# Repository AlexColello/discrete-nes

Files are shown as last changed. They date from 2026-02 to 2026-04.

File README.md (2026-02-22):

# Discrete NES - Every Gate Visible

A discrete logic implementation of the Nintendo Entertainment System where **EVERY single gate output and EVERY memory bit is visible via LED**. Watch a complete NES flip every bit in real-time.

## Project Vision

This is an educational and artistic hardware project showcasing the complete internal state of a working NES using **TI Little Logic (SN74LVC1G) in DSBGA packages** — tiny ICs with the **bare silicon die visible** on top. Thousands of exposed silicon dies interspersed with glowing 0402 SMD LEDs.

**This is one of the largest discrete logic projects ever attempted:**
- Estimated **10,000+ LEDs** across all boards
- **Thousands of single-gate ICs** (TI Little Logic, DSBGA — bare silicon visible)
- Multiple PCBs with SMD assembly
- Complete **cycle-accurate NES** implementation in visible discrete logic

## The Aesthetic

Each logic gate is a single DSBGA package (1.75 x 1.25mm) with the bare silicon wafer pattern visible on top. Between them, tiny 0402 SMD LEDs (1.0 x 0.5mm) glow to show every gate output state. The LEDs are deliberately smaller than the ICs so the silicon dies are the visual focus.

## Board Structure

- **RAM Board** - 8-byte prototype (starting point, validates DSBGA assembly)
  - ~180 DSBGA ICs, ~115 LEDs, ~115 resistors
  - ~60x80mm PCB

- **CPU Board** (2A03 - 6502-based with APU)
  - ~5,000 LEDs, ~5,000 ICs

- **PPU Board** (2C02 - Picture Processing Unit)
  - ~3,000 LEDs, ~3,000 ICs

- **Glue Logic/Interconnect Boards**

## Technology Stack

- **Logic ICs:** TI Little Logic SN74LVC1G series (DSBGA — bare silicon die visible)
- **LEDs:** 0402 SMD (smaller than ICs for aesthetic balance)
- **LED Drive:** Direct from LVC outputs (up to 24mA capable, target 2mA)
- **Schematic Generation:** Python + kiutils
- **PCB Layout:** kiutils + manual routing
- **Logic Reference:** MiSTer NES core (Verilog/SystemVerilog)
- **Design Tool:** KiCad 8.x
- **Assembly:** Solder paste stencil + hot air reflow

## Repository Structure

```
discrete-nes/
├── shared/               # Shared libraries and utilities
│   ├── kicad-lib/       # KiCad symbols, footprints, 3D models
│   └── python/          # Python generation utilities
├── boards/              # Individual board projects
│   ├── ram-prototype/   # First prototype board (8 bytes)
│   ├── cpu-2a03/        # CPU board
│   ├── ppu-2c02/        # PPU board
│   └── interconnect/    # Board interconnection
├── reference/           # FPGA reference documentation
└── tools/               # Development tools
```

## Getting Started

### Prerequisites

- Python 3.8+
- KiCad 8.x
- Git

### Setup

1. **Clone this repository:**
   ```bash
   git clone https://github.com/yourusername/discrete-nes.git
   cd discrete-nes
   ```

2. **Set up Python environment:**
   ```bash
   python -m venv venv
   source venv/bin/activate  # On Windows: venv\Scripts\activate
   pip install -r requirements.txt
   ```

3. **Review the reference documentation:**
   See `reference/README.md` for information about accessing the MiSTer NES core used as logic reference.

## Development Workflow

1. **Design circuit manually** in KiCad (first cell/module)
2. **Document the pattern** for script generation
3. **Write Python scripts** to generate repetitive structures
4. **Generate schematics** using kiutils
5. **Place components** on PCB (scripted DSBGA grid layout)
6. **Route manually** or use assisted tools
7. **Validate** with DRC/ERC
8. **Fabricate and reflow assemble**

## Current Status

**Phase 1: Project Setup** - COMPLETE

- [x] Repository structure created
- [x] Python utilities framework
- [x] Reference documentation
- [x] KiCad shared libraries (symbols/footprints)
- [x] Migration to TI Little Logic DSBGA
- [ ] RAM prototype circuit design (next)

## Power Requirements

With an LED on every gate output, power consumption is LED-dominated:

- RAM prototype (8 bytes): ~0.25A at 3.3V (~0.8W)
- Full system: ~12A+ at 3.3V (~40W)

## Educational Value

This project provides unparalleled visibility into:
- How a CPU executes instructions (watch the program counter increment!)
- Memory addressing and data flow
- Video frame generation in real-time
- Every internal state transition

Perfect for computer science education, maker spaces, and museum exhibits.

## Resources

- **MiSTer NES Core:** https://github.com/MiSTer-devel/NES_MiSTer (logic reference)
- **OpenTendo:** https://github.com/Redherring32/OpenTendo (NES reproduction PCBs)
- **NES Dev Wiki:** https://www.nesdev.org/wiki/
- **Visual 6502:** http://www.visual6502.org/

## Contributing

This is an ambitious project that will evolve over time. Contributions welcome:
- Circuit design improvements
- Python generation utilities
- Documentation
- Testing and validation

## License

TBD - To be determined

## Acknowledgments

- **MiSTer Project** - For the excellent NES core used as logic reference
- **Texas Instruments** - For the Little Logic product line
- **KiCad Project** - For the outstanding open-source EDA tools
- **Ben Eater** - For inspiring discrete logic projects
- **NES Dev Community** - For extensive documentation

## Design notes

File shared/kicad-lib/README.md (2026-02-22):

# Shared KiCad Libraries

This directory contains shared symbol and footprint libraries for the discrete NES project.

## Structure

- **symbols/** - Schematic symbols
  - `LittleLogic_LVC.kicad_sym` - TI Little Logic SN74LVC1G single-gate ICs
  - `LED_Indicators.kicad_sym` - 0402 SMD LED symbols
  - `Power_Discrete.kicad_sym` - Power connectors and regulators

- **footprints/** - PCB footprints
  - `DSBGA_Packages.pretty/` - DSBGA (NanoFree/YZP) packages for TI Little Logic
  - `LED_SMD.pretty/` - 0402 SMD LED footprints
  - `Connectors_Discrete.pretty/` - Board interconnect connectors

- **3d-models/** - 3D models for PCB visualization

## Using These Libraries

The library tables (`sym-lib-table` and `fp-lib-table`) use relative paths with `${KIPRJMOD}` to reference these shared libraries from any board project.

When creating a new board project:

1. Copy `sym-lib-table` to your project directory
2. Copy `fp-lib-table` to your project directory
3. KiCad will automatically find the shared libraries

## Creating New Symbols/Footprints

New symbols and footprints can be added using KiCad's library editors or programmatically using kiutils.

### Common Components Needed:

**Logic Gates (1 gate per DSBGA package):**
- SN74LVC1G00 - Single 2-input NAND (YZP, 5-ball)
- SN74LVC1G02 - Single 2-input NOR (YZP, 5-ball)
- SN74LVC1G04 - Single Inverter (YZP, 5-ball)
- SN74LVC1G08 - Single 2-input AND (YZP, 5-ball)
- SN74LVC1G11 - Single 3-input AND (YZP, 6-ball)
- SN74LVC1G32 - Single 2-input OR (YZP, 5-ball)
- SN74LVC1G86 - Single 2-input XOR (YZP, 5-ball)

**Flip-Flops:**
- SN74LVC1G79 - Single D flip-flop, Q only (YZP, 5-ball DSBGA)
- SN74LVC1G74 - Single D flip-flop, Q/Q-bar/preset/clear (DQE, 8-pin X2SON)

**Buffers and Drivers:**
- SN74LVC1G07 - Single buffer, open drain (YZP, 5-ball)
- SN74LVC1G125 - Single tri-state buffer (YZP, 5-ball)

**LEDs:**
- 0402 SMD LEDs (various colors)
- 0402 SMD resistors for current limiting

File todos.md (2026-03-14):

# Discrete NES - TODOs

## RAM Prototype - PCB (Phase 2 Step 3)

### Layout issues
- [x] **Layer test table In1 row broken** — fixed: added In1.Cu copper pour zone for the In1 Fill row (was missing because In1.Cu has no full-board zone unlike B.Cu/In2.Cu)
- [x] **COL_SEL and DEC4 headers misplaced** — fixed: J3 (COL_SEL) moved from test grid area to below column_select group; J2/J4 (DEC3/DEC4) remain near addr_decoder/control_logic area
- [x] **Column select LEDs need nicer presentation** — fixed: 16 output LEDs (COL_SEL_0-15) in a dedicated row above the level-2 ANDs (3.5mm gap), remaining rows keep inline LEDs
- [x] **Row control read/write gates layout** — fixed: write + read gates now horizontal (side by side), stride matched to byte row stride (7.0mm) so each row_ctrl block aligns with its byte row
- [x] **Extra spacing on byte silkscreen outlines** — fixed: reduced SILK_MARGIN from 3.0mm to 1.5mm
- [ ] **Layer test table: add hashed fill row** — add a row demonstrating hashed/crosshatch copper fill pattern

### Pre-routing rework needed
- [ ] **NAND routing rework for IC_CELL_H=3.0** — NAND local connections (preroute_nand_connections) are skipped and left to the autorouter because escape path offsets were tuned for IC_CELL_H=3.5. Needs full rework for current 3.0 geometry (generate_pcb.py:2325-2329)
- [ ] **DFF->Buffer routing** — currently skipped (autorouter via In1.Cu). Data bus via at ic_cx-0.50 leaves 0mm clearance to BUF A pin on F.Cu, so this must go through In1.Cu (generate_pcb.py:2339-2341)
- [ ] **D* data bus fanout prerouting** — preroute the fanout of D0-D7 data bus traces to byte groups
- [ ] **Column select fanout prerouting** — preroute the COL_SEL signal distribution traces
- [ ] **Row select trace prerouting** — locally preroute all ROW_SEL traces from row control to byte groups. Must happen after bytes are fully locally routed (depends on NAND, DFF->Buffer, and data bus prerouting being done first)

### Footprint rework
- [x] **Create custom DSBGA footprints** — done: removed silkscreen pin-1 triangle, reduced courtyard to 0.3mm offset from chip outline (DSBGA-5: ±0.75×±1.0, DSBGA-6: ±0.8×±1.0, DSBGA-8: ±0.8×±1.3)

- [ ] **Pin connector 3D models rotated 180°** — all pin header connectors (J1-J4) have their 3D model rotated 180° around the square pad in the 3D viewer. Need to fix the model rotation in the footprint or placement
- [ ] **Add 3D models for DSBGA-5 and DSBGA-6 footprints** — custom footprints currently lack 3D models for KiCad 3D viewer
- [ ] **Investigate moving resistors to front of board** — currently on B.Cu for space reasons, but this makes assembly and rework harder. Explore using a smaller resistor footprint (e.g., 0201) to fit R on F.Cu alongside the LED

### Post-footprint-rework
- [ ] **Compress PCB layout** — once custom footprints with tighter courtyards are in place, reduce component spacing / cell dimensions to take advantage of the smaller footprints

### Autorouter / manual routing
- [ ] **Run FreeRouting autorouter** on current PCB to complete remaining unrouted nets
- [ ] **Verify post-routing DRC** — run `verify_pcb.py --post-routing` after routing completes
- [ ] **Review routed result** — check trace quality, 45-degree angles, no unnecessary vias

### PCB validation
- [ ] **Fabrication review** — verify board meets Elecrow specs (min via 0.8mm/0.4mm, trace/space, etc.)
- [ ] **Add JLCPCB DRC rules** — include JLCPCB design rule checks alongside Elecrow for fab flexibility
- [ ] **Power distribution review** — check VCC/GND plane integrity, via current capacity
- [ ] **Generate gerbers** and do final visual inspection
- [ ] **Generate BOM** for ordering

## RAM Prototype - Schematic

### Signal ordering / spacing
- [x] **Row select pin order vs inverter order swapped** — fixed: reversed A0-A6 order on addr_decoder sheet block and internally (A6 at top, A0 at bottom) to match connector visual order at 180°
- [x] **More space between connector and logic** — fixed: increased PCB gap from GROUP_GAP_X to GROUP_GAP_X*3 (6mm extra between connector group and addr_decoder)

### Wire routing / overlaps
- [ ] **Wire overlaps throughout** — verify_schematics.py check passes but visual issues may remain. Needs user review in KiCad to identify specific problem areas
- [ ] **Root sheet routing nonsensical** — wire routing on the root sheet doesn't make sense, looks like connector pins are not being positioned/moved correctly
- [ ] **Pin names missing on connector** — connector pins should have visible names next to them
- [ ] **Hierarchical labels outside sheet margins** — verify_schematics.py check passes but visual issues may remain. Needs user review in KiCad to identify specific problem areas

### PCB generate script
- [ ] **Fix layout ASCII art in generate_pcb.py** — the ASCII art diagram at the top of the file doesn't accurately reflect the current board layout

### Visual / layout issues
- [ ] **Text drawn on top of components** — component text (references, values) overlapping other components where it shouldn't be
- [ ] **VCC/GND symbols touching tip-to-tip** — verify_schematics.py doesn't catch this. Needs user review in KiCad to identify specific problem areas

### Component selection
- [ ] **Choose LED part numbers and colors** — select specific 0402 LED parts. Consider using different colors to visually distinguish gate types or functional purposes (e.g., address decoder vs data path vs control signals)
- [ ] **Choose resistor values** — calculate and select appropriate current-limiting resistor values for each LED color at 3.3V (different Vf per color means different R values)

### Architecture improvement
- [ ] **Simplify LED indicators** — investigate using a symbol, sub-sheet, or other encapsulation method to hold the LED+resistor chain so that LEDs don't have to be drawn inline in every gate logic sheet. Would significantly reduce schematic clutter and simplify the generate scripts

## RAM Prototype - Fabrication (Phase 2 Step 5)

- [ ] Order PCBs + solder paste stencil
- [ ] Order components (DSBGA ICs, 0402 LEDs, 0402 resistors, pin headers)
- [ ] Cost estimation for prototype run
- [ ] Reflow assembly and test

## Shared Library (kicad_gen)

- [x] **DSBGA footprint files modified** — these are auto-generated by generate_pcb.py on each run (create_dsbga_footprints), no manual commit needed
- [ ] Consider adding automated tests for kicad_gen modules

## Future Boards

### CPU (2A03)
- [ ] Study MiSTer NES core Verilog for 6502 CPU
- [ ] Gate-level synthesis (Yosys?) of CPU logic
- [ ] Map to SN74LVC1G discrete gates
- [ ] Plan power distribution for ~5000 LEDs (~6A at 3.3V)

### PPU (2C02)
- [ ] Study MiSTer NES core Verilog for PPU
- [ ] Gate-level synthesis of PPU logic
- [ ] Plan power distribution for ~3000 LEDs (~4A at 3.3V)

### System Integration
- [ ] Board interconnect design (backplane or cable)
- [ ] System-level power distribution (12A+ at 3.3V total)
- [ ] Clock distribution across boards

## HDL Parser / Verilog-to-Gates

- [ ] Enhance `verilog_to_gates.py` for real synthesis
- [ ] Evaluate Yosys as synthesis backend
- [ ] Test with MiSTer NES modules

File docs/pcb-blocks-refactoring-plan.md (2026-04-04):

# Refactoring Plan: Composable PCB Layout Block Classes

## Context

`generate_pcb.py` is 4868 lines with 44 functions. The layout and prerouting logic is monolithic — every byte group, decoder column, and routing pattern is handled by standalone functions that take raw `(pcb, netlist_data)` and rely on global knowledge of where everything was placed. This makes it impossible to reuse blocks across boards (the full 2KB board at `boards/ram/` has no PCB generation at all yet — it would require copy-pasting thousands of lines).

The core problem: **there's no object that represents "a placed group of components with its routing"**. Layout positions are computed in `main()`, prerouting functions re-discover positions by scanning all footprints, and there's no way to compose a byte group + decoder + bus routing as reusable units.

## Approach

Introduce block classes that own their layout, placement, and prerouting. Each block:
- Knows its own relative component positions
- Places itself on a `PCBBuilder` at an absolute (x, y) origin
- Pre-routes its internal connections
- Exposes interface points (pin positions, bus stubs) for inter-block wiring

### Key Files

| File | Change |
|---|---|
| `shared/python/kicad_gen/pcb_blocks.py` | **NEW** — Block base class + concrete blocks |
| `shared/python/kicad_gen/__init__.py` | Export new block classes |
| `boards/ram-prototype/scripts/generate_pcb.py` | Refactor to use blocks |

## Block Class Design

### Base: `PCBBlock`

```python
class PCBBlock:
    """Base class for a composable PCB component group."""
    
    def __init__(self):
        self.origin = (0.0, 0.0)       # absolute placement origin
        self._placements = []           # [(comp_dict, rel_x, rel_y), ...]
        self._placed_refs = []          # refs after placement
    
    def layout(self, components):
        """Compute relative placements from netlist components. Sets self._placements."""
        raise NotImplementedError
    
    def place(self, pcb, x, y, netlist_data):
        """Place all components at absolute (x, y) origin. Returns list of refs placed."""
        self.origin = (x, y)
        ...
    
    def preroute(self, pcb, netlist_data):
        """Pre-route internal connections. Called after place()."""
        pass
    
    def get_bounds(self):
        """Return (min_x, min_y, max_x, max_y) in absolute coords."""
        ...
    
    def get_pin(self, ref, pad):
        """Get absolute position of a pad. Shortcut for pcb.get_pad_position()."""
        ...
    
    def get_interface(self):
        """Return dict of named interface points for inter-block wiring."""
        return {}
```

### `ByteGroupBlock` — The highest-value abstraction

Owns: 1 NAND (74LVC2G00) + 8 DFF + 8 BUF + 18 LEDs + 18 Rs = ~54 components per byte.

Currently spread across:
- `layout_byte_group()` (~80 lines) — relative positioning
- `preroute_dff_to_buffer()` (~120 lines) — DFF Q → BUF A via In1.Cu
- `preroute_dff_buf_gnd()` (~60 lines) — shared GND Z-route
- `preroute_dff_buf_data()` (~65 lines) — data pin mirrored Z-route
- `preroute_dff_buf_vcc()` (~80 lines) — VCC L-route via In2.Cu
- `preroute_clk_fanout()` (~65 lines) — CLK horizontal bus
- `preroute_oe_fanout()` (~65 lines) — OE horizontal bus  
- `preroute_nand_connections()` (~280 lines) — NAND output/input routing
- `preroute_nand_leds()` (~110 lines) — NAND LED routing
- `preroute_ic_to_led()` (DFF/BUF portions, ~50 lines) — IC→LED anode
- Parts of `preroute_led_to_resistor()`, `preroute_r_gnd()`, `preroute_power_vias()`

Total: ~1000 lines of byte-specific code → encapsulated as one class with `layout()`, `place()`, `preroute()`.

```python
class ByteGroupBlock(PCBBlock):
    def layout(self, components):
        """Current layout_byte_group() logic."""
        
    def preroute(self, pcb, netlist_data):
        """All internal byte routing:
        - DFF-BUF pairs (Q→A, GND, VCC, data)
        - CLK fanout bus
        - OE fanout bus  
        - NAND connections + NAND LEDs
        - IC→LED, LED→R, R→GND for byte components
        """
    
    def get_interface(self):
        """Returns positions for inter-block wiring:
        - clk_bus: (x_start, x_end, y) — CLK bus entry point
        - oe_bus: (x_start, x_end, y) — OE bus entry point
        - nand_colsel_pin: (x, y) — COL_SEL input to NAND
        - nand_wen_pin: (x, y) — WRITE_EN input to NAND
        - nand_ren_pin: (x, y) — READ_EN input to NAND
        - dff_data_vias: [(x, y, net), ...] — D0-D7 data bus via positions
        """
```

### `DecoderColumnBlock` — Vertical IC column

Owns: N ICs + N LEDs + N Rs in a vertical column with configurable spacing.

Currently: `_place_col()` closure in `main()` + the addr_decoder / column_select custom layout blocks.

```python
class DecoderColumnBlock(PCBBlock):
    def __init__(self, cell_h=4.0, led_offset_x=1.5, r_horiz_offset=1.86):
        ...
    
    def layout(self, ic_cells, total_h=None, ys=None):
        """Place cells vertically centered within total_h, or at explicit ys."""
    
    def preroute(self, pcb, netlist_data):
        """IC→LED, LED→R, power vias for this column."""
    
    def get_interface(self):
        """Returns IC pin positions by index for inter-column wiring."""
```

### `DecoderBlock` — Multi-column decoder (addr_decoder or column_select)

Composes multiple `DecoderColumnBlock`s:

```python
class DecoderBlock(PCBBlock):
    def __init__(self, column_configs):
        """column_configs: list of (num_cells, cell_h, col_spacing) per column."""
        self.columns = []  # list of DecoderColumnBlock
    
    def layout(self, components):
        """Split components into columns, layout each."""
        
    def preroute(self, pcb, netlist_data):
        """Route all columns' internal connections."""
```

### `RowControlBlock` — Vertical AND gate pair

Owns: 2 ANDs + 2 LEDs + 2 Rs.

```python
class RowControlBlock(PCBBlock):
    def __init__(self, gate_spacing=2.3):
        ...
```

### `ConnectorBlock` — Connector + bus indicator LEDs

Owns: 1 connector + matched LED+R pairs aligned to pin Y positions.

### `PowerSupplyBlock` — Buck converter + passives + zones

Owns: TPS546D24A + caps + inductor + resistors + copper pour zones.

## Inter-Block Wiring

After all blocks are placed and internally prerouted, the remaining preroute functions handle inter-block connections. These stay as functions (not methods) because they span multiple blocks:

- `preroute_enable_buses()` — row_ctrl → byte CLK/OE buses
- `preroute_ctrl_enable_trunks()` — control_logic → row_ctrl
- `preroute_col_sel_vias()` / `preroute_colsel_fanout()` — column_select → bytes
- `preroute_column_dbus()` / `preroute_dbus_fanout()` / `preroute_dbus_to_connector()` — data bus across all bytes
- `preroute_connector_leds()` — connector → bus LEDs
- `preroute_coladdr_to_colsel()` — connector → column_select

These inter-block routers can use `block.get_interface()` to discover connection points instead of scanning all footprints.

## How `main()` Changes

Before (pseudocode):
```python
# 200 lines computing layouts for each group type (custom per group)
# 200 lines computing absolute positions
# 200 lines placing components with for loops
# 30 lines calling 20+ preroute functions
```

After:
```python
# Create blocks
bytes = [ByteGroupBlock() for _ in range(8)]
decoder = DecoderBlock(addr_decoder_config)
col_select = DecoderBlock(col_select_config)  
row_ctrls = [RowControlBlock() for _ in range(4)]
connector = ConnectorBlock()
power = PowerSupplyBlock()

# Layout (from netlist components)
for i, name in enumerate(byte_names):
    bytes[i].layout(groups[name])
decoder.layout(groups["addr_decoder"])
# ... etc

# Compute positions (board-specific arrangement)
# ... ~50 lines of position math (reduced from ~200)

# Place + preroute all blocks
for block in all_blocks:
    block.place(pcb, x, y, netlist_data)
    block.preroute(pcb, netlist_data)

# Inter-block routing
route_enable_buses(pcb, row_ctrls, bytes, netlist_data)
route_data_bus(pcb, bytes, connector, netlist_data)
# ... etc
```

## Implementation Order

1. **Create `pcb_blocks.py`** with `PCBBlock` base class and `ByteGroupBlock`
   - Move `layout_byte_group()` → `ByteGroupBlock.layout()`
   - Move byte-specific preroute functions → `ByteGroupBlock.preroute()`
   - Wire up `get_interface()` returning bus stubs and NAND pins

2. **Add `DecoderColumnBlock`** and **`DecoderBlock`**
   - Move `_place_col()` and addr_decoder/column_select layout → block classes
   - Move IC→LED, LED→R, power via routing for decoder ICs

3. **Add `RowControlBlock`**, **`ConnectorBlock`**, **`PowerSupplyBlock`**

4. **Refactor `main()`** to compose blocks
   - Keep inter-block routing as standalone functions that take block references
   - Inter-block routers use `block.get_interface()` instead of footprint scanning

5. **Update `__init__.py`** exports

6. **Verify**: run `generate_pcb.py` → `verify_pcb.py` → 0 errors, 0 warnings

## Also (minor, schematic side)

Move `_add_sheet_block` / `_sheet_height` / `_pin_y` from board scripts to `SchematicBuilder` as `add_sheet_block()` / `sheet_height()` / `sheet_pin_y()` — eliminates the only duplication between the two board schematic scripts.

## What Does NOT Change

- `PCBBuilder` class in `pcb.py` — stays as-is (it's the low-level API)
- `route_pcb.py` — autorouter pipeline, not affected
- `verify_pcb.py` / `verify_schematics.py` — verification scripts
- `debug_1byte.py` — will need updating to use `ByteGroupBlock` instead of importing raw functions
- Schematic generation (`generate_ram.py`) — minimal changes (just the `add_sheet_block` move)

## Verification

Full pipeline — must pass all three stages:

```bash
cd boards/ram-prototype
source ../../venv/Scripts/activate

# 1. Generate PCB + pre-routing DRC
python scripts/generate_pcb.py
python scripts/verify_pcb.py

# 2. Autoroute via FreeRouting
export PATH="/c/Program Files/Java/jdk-21.0.10/bin:$PATH"
python scripts/route_pcb.py

# 3. Post-routing DRC (stricter — checks completed traces)
python scripts/verify_pcb.py --post-routing
```

**Pre-routing target:** 0 errors / 0 warnings (same as current state).

**Post-routing target:** No new violations vs current baseline (2 cosmetic `solder_mask_bridge` + 2 `isolated_copper` warnings on Default/PCBWay/Elecrow rules — 0 real errors). Any new `unconnected_items`, `shorting_items`, or `clearance` errors means the refactoring broke routing.

The autorouter step is critical — preroute changes that look clean in isolation can cause FreeRouting to fail completing remaining traces or produce clearance violations. The post-routing DRC is the definitive pass/fail gate.

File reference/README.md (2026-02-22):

# FPGA NES Reference Implementation

This directory contains documentation and links to the MiSTer NES core, which serves as the logic reference for the discrete NES implementation.

## MiSTer NES Core

**Repository:** https://github.com/MiSTer-devel/NES_MiSTer

### Accessing the Source

The MiSTer NES core is NOT included as a git submodule. To access the source code:

```bash
# Clone the repository to your local machine
git clone https://github.com/MiSTer-devel/NES_MiSTer.git

# Or download a specific release
# https://github.com/MiSTer-devel/NES_MiSTer/releases
```

### Repository Structure

Key Verilog files for reference:

- **CPU (2A03/6502):**
  - Look for 6502/CPU implementation files
  - APU (Audio Processing Unit) implementation

- **PPU (2C02):**
  - Picture Processing Unit implementation
  - Sprite and background rendering logic

- **Memory Controllers:**
  - RAM interface
  - Mapper implementations

### Using as Logic Reference

The MiSTer core is written in Verilog/SystemVerilog. To convert to discrete logic:

1. **Identify the module** you want to implement (e.g., a register, ALU, decoder)
2. **Analyze the gate-level logic** - may need to synthesize to gate-level netlist
3. **Map gates to TI Little Logic (SN74LVC1G)** using the tools in `shared/python/hdl_parser/`
4. **Add LED indicators** to every gate output
5. **Generate KiCad schematics** using the tools in `shared/python/kicad_gen/`

### Additional References

- **NES Dev Wiki:** https://www.nesdev.org/wiki/
- **6502 Documentation:** http://www.6502.org/
- **Visual 6502:** http://www.visual6502.org/ (transistor-level simulation)

## License Information

The MiSTer NES core is based on FPGANES by Ludvig Strigeus. Check the MiSTer repository for specific license terms.

Our discrete implementation is a separate work that references the logic implementation but does not include the MiSTer code directly.

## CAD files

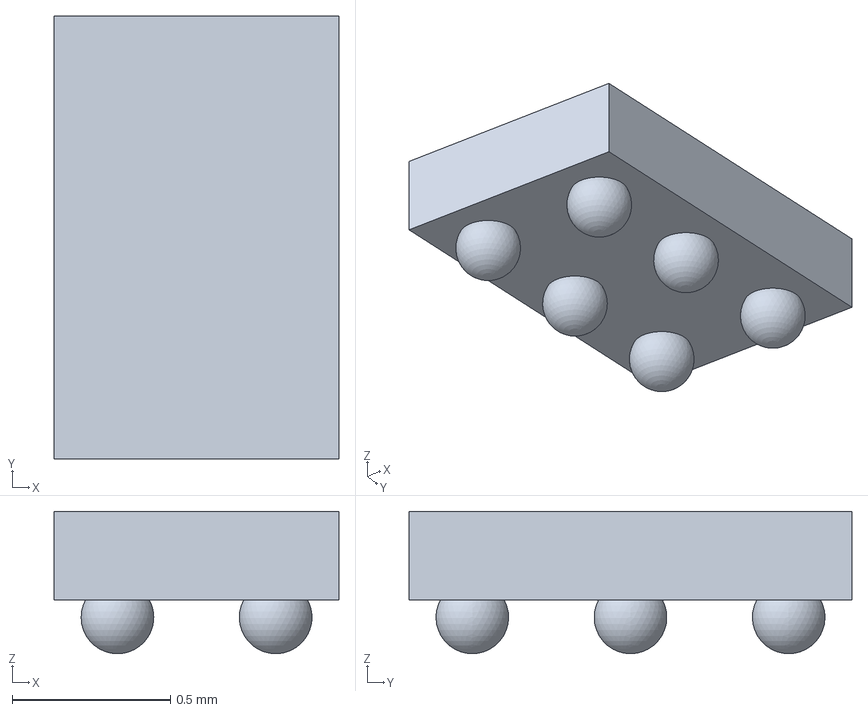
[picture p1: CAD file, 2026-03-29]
shared/kicad-lib/3d-models/Texas_DSBGA-6_0.9x1.4mm_Layout2x3_P0.5mm.step
0.9 x 1.40 x 0.45 mm

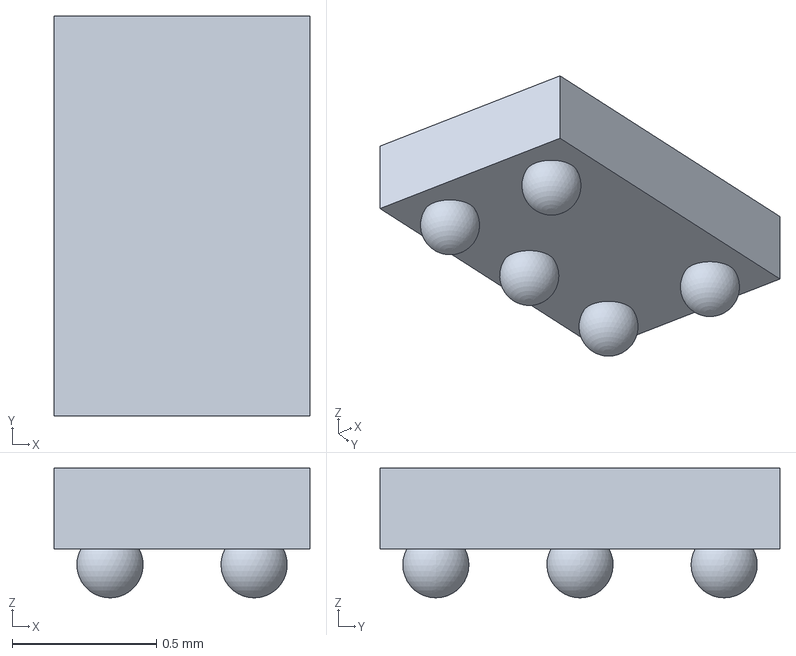
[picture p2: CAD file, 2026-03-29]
shared/kicad-lib/3d-models/Texas_DSBGA-5_0.8875x1.3875mm_Layout2x3_P0.5mm.step
0.887 x 1.39 x 0.45 mm

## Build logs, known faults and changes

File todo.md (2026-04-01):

# Discrete NES - TODOs

## RAM Prototype - PCB (Phase 2 Step 3)

### Layout issues
- [x] **Layer test table In1 row broken** — fixed: added In1.Cu copper pour zone for the In1 Fill row (was missing because In1.Cu has no full-board zone unlike B.Cu/In2.Cu)
- [x] **COL_SEL and DEC4 headers misplaced** — fixed: J3 (COL_SEL) moved from test grid area to below column_select group; J2/J4 (DEC3/DEC4) remain near addr_decoder/control_logic area
- [x] **Column select LEDs need nicer presentation** — fixed: 16 output LEDs (COL_SEL_0-15) in a dedicated row above the level-2 ANDs (3.5mm gap), remaining rows keep inline LEDs
- [x] **Row control read/write gates layout** — fixed: write + read gates now horizontal (side by side), stride matched to byte row stride (7.0mm) so each row_ctrl block aligns with its byte row
- [x] **Extra spacing on byte silkscreen outlines** — fixed: reduced SILK_MARGIN from 3.0mm to 1.5mm
- [ ] **Layer test table: add hashed fill row** — add a row demonstrating hashed/crosshatch copper fill pattern

### Pre-routing
- [x] **Pin 2 escape stubs** — all DSBGA-5 ICs (including row_ctrl and control_logic) now get center-escape stubs
- [x] **WRITE_ACTIVE trunk** — continuous vertical In1.Cu line; READ_EN vias offset right to avoid crossing
- [x] **COL_SEL fully local routed** — F.Cu from terminus vias to column select ICs with chamfered 45° paths
- [x] **D* data bus fanout** — In1.Cu trunks + F.Cu horizontal bus below byte grid, covered by routing keepout
- [x] **Column select fanout** — In1.Cu trunks extended below D* bus with F.Cu connection to column select ICs
- [x] **NAND LED traces** — cathode-to-R and anode connections with exact pad coordinate precision (3 decimal)
- [x] **Connector LED pre-routing** — J1 to LED + fanout stubs
- [ ] **NAND routing rework for IC_CELL_H=3.0** — NAND local connections (preroute_nand_connections) partially reworked but some escape offsets still tuned for 3.5. Autorouter handles remaining
- [ ] **Row select trace prerouting** — locally preroute all ROW_SEL traces from row control to byte groups

### Autorouter / routing
- [x] **FreeRouting autorouter pipeline** — single-pass routing with DSN clearance fixup
- [x] **DSN clearance rules** — global 200µm (PCBWay pad-to-track), smd_smd 154µm, via_via 500µm (all rule blocks), via_smd/via_pin 254µm
- [x] **Connector net class** — J2/J3/J4 nets in "Connectors" class for potential two-pass routing
- [x] **Routing keepouts** — ram_grid (byte area + D* bus), test_grid, connector+LED area
- [x] **Dangling track cleanup** — up to 50mm length, multi-pass
- [x] **Raw post-import PCB saved** — verify_output/ram_routed_raw.kicad_pcb for inspection
- [x] **Post-routing DRC clean** — 2 solder_mask_bridge (cosmetic) + 2 isolated_copper (warnings) only

### Silkscreen
- [x] **Strip R + DSBGA-8 silk** — 0402 resistor and DSBGA-8 silkscreen removed (too dense for 0.15mm clearance). DSBGA-5/6 silk kept
- [x] **LED polarity dot** — moved from F.SilkS to F.Fab (visible in KiCad, no silk_overlap at any rotation)
- [x] **Footprint text hidden** — all Reference/Value text hidden on F.SilkS and F.Fab
- [x] **silk_overlap removed from skip list** — now passes clean without suppression

### Footprint rework
- [x] **Create custom DSBGA footprints** — done: removed silkscreen pin-1 triangle, reduced courtyard to 0.3mm offset from chip outline
- [x] **Pin connector 3D models rotated 180°** — fixed: added 180° Z rotation to 3D model for B.Cu connectors
- [ ] **Add 3D models for DSBGA-5 and DSBGA-6 footprints** — custom footprints currently lack 3D models for KiCad 3D viewer
- [ ] **Investigate moving resistors to front of board** — currently on B.Cu for space reasons, explore 0201 footprint

### PCB validation
- [x] **Post-routing DRC** — 0 real errors across Default/PCBWay/Elecrow rules
- [ ] **Fabrication review** — verify board meets Elecrow specs (min via 0.8mm/0.4mm, trace/space, etc.)
- [ ] **Power distribution review** — check VCC/GND plane integrity, via current capacity
- [ ] **Generate gerbers** and do final visual inspection
- [ ] **Generate BOM** for ordering

## RAM Prototype - Schematic

### Signal ordering / spacing
- [x] **Row select pin order vs inverter order swapped** — fixed
- [x] **More space between connector and logic** — fixed
- [x] **Connector control pin order** — nCE/nOE/nWE top-to-bottom (pin 8/7/6)

### Wire routing / overlaps
- [ ] **Wire overlaps throughout** — verify_schematics.py check passes but visual issues may remain
- [ ] **Root sheet routing nonsensical** — needs user review in KiCad
- [ ] **Pin names missing on connector** — connector pins should have visible names
- [ ] **Hierarchical labels outside sheet margins** — needs user review

### PCB generate script
- [ ] **Fix layout ASCII art in generate_pcb.py** — doesn't accurately reflect current board layout

### Visual / layout issues
- [ ] **Text drawn on top of components** — overlapping references/values
- [ ] **VCC/GND symbols touching tip-to-tip** — needs user review

### Component selection
- [ ] **Choose LED part numbers and colors** — select specific 0402 LED parts
- [ ] **Update LED resistor values from 750R to 1K** in generate scripts
- [ ] **Choose resistor values per LED color** — different Vf per color

### Architecture improvement
- [ ] **Simplify LED indicators** — investigate sub-sheet encapsulation for LED+R chains

## Assembly Method

Need a custom assembly approach — a pick-and-place machine in budget range can't place all 611+ components before solder paste dries out.

**Proposed approach: tray + suction sheet**

1. **Part tray** — fixture where components are placed at leisure
2. **Suction sheet** — picks up all components and transfers to solder-pasted PCB

### Open questions
- Tray material and fabrication method
- Suction sheet mechanism
- Alignment method between tray and PCB
- Pocket depth for DSBGA vs 0402 parts
- Transfer tolerance requirements

## RAM Prototype - Fabrication (Phase 2 Step 5)

- [ ] Order PCBs + solder paste stencil
- [ ] Order components (DSBGA ICs, 0402 LEDs, 0402 resistors, pin headers)
- [ ] Cost estimation for prototype run
- [ ] Reflow assembly and test

## Shared Library (kicad_gen)

- [x] **DSBGA footprint files modified** — auto-generated by generate_pcb.py
- [x] **3-decimal precision** — get_pad_position, add_trace, _build_net_pad_index all use round(...,3)
- [x] **remove_silkscreen_graphics** — strips R/DSBGA silk from routed boards
- [ ] Consider adding automated tests for kicad_gen modules

## Future Boards

### CPU (2A03)
- [ ] Study MiSTer NES core Verilog for 6502 CPU
- [ ] Gate-level synthesis (Yosys?) of CPU logic
- [ ] Map to SN74LVC1G discrete gates
- [ ] Plan power distribution for ~5000 LEDs (~6A at 3.3V)

### PPU (2C02)
- [ ] Study MiSTer NES core Verilog for PPU
- [ ] Gate-level synthesis of PPU logic
- [ ] Plan power distribution for ~3000 LEDs (~4A at 3.3V)

### System Integration
- [ ] Board interconnect design (backplane or cable)
- [ ] System-level power distribution (12A+ at 3.3V total)
- [ ] Clock distribution across boards

## HDL Parser / Verilog-to-Gates

- [ ] Enhance `verilog_to_gates.py` for real synthesis
- [ ] Evaluate Yosys as synthesis backend
- [ ] Test with MiSTer NES modules

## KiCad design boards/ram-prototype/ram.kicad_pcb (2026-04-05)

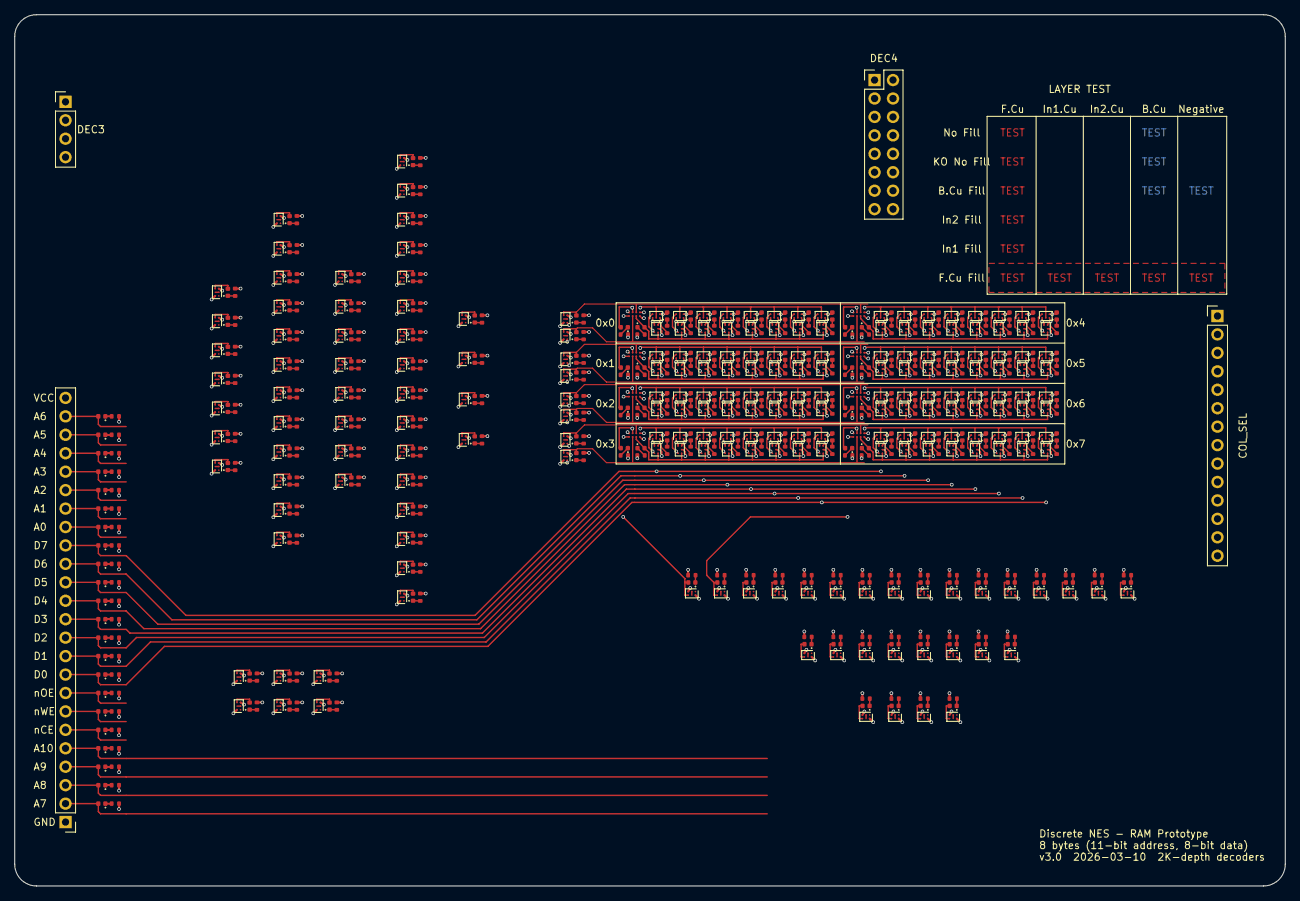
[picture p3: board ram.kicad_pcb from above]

Board: 4 copper layers, 175.0 x 120.0 mm, 611 parts (1 on the bottom side), 384 nets.

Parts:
D1, D2, D3, D4, D5, D6, D7, D8, D9, D10, D11, D12, D13, D14, D15, D16, D17, D18, D19, D20, D21, D22, D23, D24, D25, D26, D27, D28, D29, D30, D31, D32, D33, D34, D35, D36, D37, D38, D39, D40, D41, D42, D43, D44, D45, D46, D47, D48, D49, D50, D51, D52, D53, D54, D55, D56, D57, D58, D59, D60, D61, D62, D63, D64, D65, D66, D67, D68, D69, D70, D71, D72, D73, D74, D75, D76, D77, D78, D79, D80, D81, D82, D83, D84, D85, D86, D87, D88, D89, D90, D91, D92, D93, D94, D95, D96, D97, D98, D99, D100, D101, D102, D103, D104, D105, D106, D107, D108, D109, D110, D111, D112, D113, D114, D115, D116, D117, D118, D119, D120, D121, D122, D123, D124, D125, D126, D127, D128, D129, D130, D131, D132, D133, D134, D135, D136, D137, D138, D139, D140, D141, D142, D143, D144, D145, D146, D147, D148, D149, D150, D151, D152, D153, D154, D155, D156, D157, D158, D159, D160, D161, D162, D163, D164, D165, D166, D167, D168, D169, D170, D171, D172, D173, D174, D175, D176, D177, D178, D179, D180, D181, D182, D183, D184, D185, D187, D188, D189, D190, D191, D192: LED_0402_1005Metric
J1: PinHeader_1x24_P2.54mm_Vertical
J2: PinHeader_1x04_P2.54mm_Vertical
J3: PinHeader_1x14_P2.54mm_Vertical
J4: PinHeader_2x08_P2.54mm_Vertical
R1, R2, R3, R4, R5, R6, R7, R8, R9, R10, R11, R12, R13, R14, R15, R16, R17, R18, R19, R20, R21, R22, R23, R24, R25, R26, R27, R28, R29, R30, R31, R32, R33, R34, R35, R36, R37, R38, R39, R40, R41, R42, R43, R44, R45, R46, R47, R48, R49, R50, R51, R52, R53, R54, R55, R56, R57, R58, R59, R60, R61, R62, R63, R64, R65, R66, R67, R68, R69, R70, R71, R72, R73, R74, R75, R76, R77, R78, R79, R80, R81, R82, R83, R84, R85, R86, R87, R88, R89, R90, R91, R92, R93, R94, R95, R96, R97, R98, R99, R100, R101, R102, R103, R104, R105, R106, R107, R108, R109, R110, R111, R112, R113, R114, R115, R116, R117, R118, R119, R120, R121, R122, R123, R124, R125, R126, R127, R128, R129, R130, R131, R132, R133, R134, R135, R136, R137, R138, R139, R140, R141, R142, R143, R144, R145, R146, R147, R148, R149, R150, R151, R152, R153, R154, R155, R156, R157, R158, R159, R160, R161, R162, R163, R164, R165, R166, R167, R168, R169, R170, R171, R172, R173, R174, R175, R176, R177, R178, R179, R180, R181, R182, R183, R184, R185, R190, R191, R192, R193, R194, R195: R_0402_1005Metric
U1, U2, U3, U4, U5, U6, U7, U8, U9, U10, U11, U12, U13, U14, U15, U16, U17, U18, U19, U20, U21, U22, U23, U24, U25, U26, U27, U28, U29, U30, U31, U32, U33, U34, U35, U36, U37, U38, U39, U40, U41, U42, U43, U44, U45, U46, U47, U48, U49, U50, U51, U52, U53, U54, U55, U56, U57, U58, U59, U60, U61, U62, U63, U64, U65, U66, U67, U68, U69, U70, U71, U72, U73, U74, U75, U76, U77, U78, U79, U80, U81, U82, U83, U92, U93, U94, U95, U96, U97, U98, U99, U100, U101, U102, U103, U104, U105, U106, U107, U108, U109, U110, U111, U112, U113, U114, U115, U116, U117, U118, U119, U120, U121, U122, U123, U124, U125, U126, U127, U128, U129, U130, U131, U132, U133, U134, U135, U136, U137, U138, U139, U140, U141, U142, U143, U144, U145, U146, U147, U148, U149, U150, U151, U152, U153, U154, U155, U156, U157, U158, U159, U160, U161, U162, U163, U164, U165, U166, U167, U168, U169, U170, U171, U172, U173, U174, U175, U176, U177, U178, U179, U180, U181, U182, U183, U184, U185, U186, U187, U188, U189, U190, U191, U192, U193, U194, U195, U196, U197, U198, U199, U200, U201, U202, U203, U204, U205, U206, U207, U208, U209, U210, U211, U212, U213, U214, U215, U216, U217, U218, U219, U221, U222, U223, U224, U225, U226: DSBGA\-5_NumericPads; DSBGA-5_NumericPads
U84, U85, U86, U87, U88, U89, U90, U91: DSBGA\-8_NumericPads; DSBGA-8_NumericPads

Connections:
/Address Decoder/A0: D7.2, J1.17, U7.2, U13.2, U15.2, U17.2, U19.2
/Address Decoder/A1: D6.2, J1.18, U6.2, U9.2, U11.2
/Address Decoder/A2: D5.2, J1.19, U5.2, U10.1, U11.1
/Address Decoder/A3: D4.2, J1.20, U4.2, U21.2, U23.2
/Address Decoder/A4: D3.2, J1.21, U3.2, U22.1, U23.1
/Address Decoder/A5: D2.2, J1.22, U2.2, U25.2, U27.2
/Address Decoder/A6: D1.2, J1.23, U1.2, U26.1, U27.1
/Address Decoder/DEC3_0: D34.2, U12.4, U44.1
/Address Decoder/DEC3_1: D35.2, U13.4, U45.1
/Address Decoder/DEC3_2: D36.2, U14.4, U46.1
/Address Decoder/DEC3_3: D37.2, U15.4, U47.1
/Address Decoder/DEC4_0: D50.2, U28.4, U44.2, U45.2, U46.2, U47.2
/Address Decoder/G0: D30.2, U8.4, U12.1, U13.1
/Address Decoder/G1: D31.2, U9.4, U14.1, U15.1
/Address Decoder/G2: D32.2, U10.4, U16.1, U17.1
/Address Decoder/G3: D33.2, U11.4, U18.1, U19.1
/Address Decoder/HA0: D42.2, U20.4, U28.2, U32.2, U36.2, U40.2
/Address Decoder/HA1: D43.2, U21.4, U29.2, U33.2, U37.2, U41.2
/Address Decoder/HA2: D44.2, U22.4, U30.2, U34.2, U38.2, U42.2
/Address Decoder/HA3: D45.2, U23.4, U31.2, U35.2, U39.2, U43.2
/Address Decoder/HB0: D46.2, U24.4, U28.1, U29.1, U30.1, U31.1
/Address Decoder/HB1: D47.2, U25.4, U32.1, U33.1, U34.1, U35.1
/Address Decoder/HB2: D48.2, U26.4, U36.1, U37.1, U38.1, U39.1
/Address Decoder/HB3: D49.2, U27.4, U40.1, U41.1, U42.1, U43.1
/Address Decoder/ROW_SEL_0: D66.2, U44.4, U76.2, U80.2
/Address Decoder/ROW_SEL_1: D67.2, U45.4, U77.2, U81.2
/Address Decoder/ROW_SEL_2: D68.2, U46.4, U78.2, U82.2
/Address Decoder/ROW_SEL_3: D69.2, U47.4, U79.2, U83.2
/Address Decoder/nA0: D29.2, U7.4, U12.2, U14.2, U16.2, U18.2
/Address Decoder/nA1: D28.2, U6.4, U8.2, U10.2
/Address Decoder/nA2: D27.2, U5.4, U8.1, U9.1
/Address Decoder/nA3: D26.2, U4.4, U20.2, U22.2
/Address Decoder/nA4: D25.2, U3.4, U20.1, U21.1
/Address Decoder/nA5: D24.2, U2.4, U24.2, U26.2
/Address Decoder/nA6: D23.2, U1.4, U24.1, U25.1
/COL_SEL_0: D82.2, U60.4, U84.1, U84.5, U85.1, U85.5, U86.1, U86.5, U87.1, U87.5
/COL_SEL_1: D83.2, U61.4, U88.1, U88.5, U89.1, U89.5, U90.1, U90.5, U91.1, U91.5
/COL_SEL_2: D84.2, J3.1, U62.4
/COL_SEL_3: D85.2, J3.2, U63.4
/COL_SEL_4: D86.2, J3.3, U64.4
/COL_SEL_5: D87.2, J3.4, U65.4
/COL_SEL_6: D88.2, J3.5, U66.4
/COL_SEL_7: D89.2, J3.6, U67.4
/COL_SEL_8: D90.2, J3.7, U68.4
/COL_SEL_9: D91.2, J3.8, U69.4
/COL_SEL_10: D92.2, J3.9, U70.4
/COL_SEL_11: D93.2, J3.10, U71.4
/COL_SEL_12: D94.2, J3.11, U72.4
/COL_SEL_13: D95.2, J3.12, U73.4
/COL_SEL_14: D96.2, J3.13, U74.4
/COL_SEL_15: D97.2, J3.14, U75.4
/Column Select/A7: D22.2, J1.2, U48.2, U53.2, U55.2
/Column Select/A8: D21.2, J1.3, U49.2, U54.1, U55.1
/Column Select/A9: D20.2, J1.4, U50.2, U57.2, U59.2
/Column Select/A10: D19.2, J1.5, U51.2, U58.1, U59.1
/Column Select/GA0: D74.2, U52.4, U60.2, U64.2, U68.2, U72.2
/Column Select/GA1: D75.2, U53.4, U61.2, U65.2, U69.2, U73.2
/Column Select/GA2: D76.2, U54.4, U62.2, U66.2, U70.2, U74.2
/Column Select/GA3: D77.2, U55.4, U63.2, U67.2, U71.2, U75.2
/Column Select/GB0: D78.2, U56.4, U60.1, U61.1, U62.1, U63.1
/Column Select/GB1: D79.2, U57.4, U64.1, U65.1, U66.1, U67.1
/Column Select/GB2: D80.2, U58.4, U68.1, U69.1, U70.1, U71.1
/Column Select/GB3: D81.2, U59.4, U72.1, U73.1, U74.1, U75.1
/D0: D15.2, J1.9, U92.1, U93.1, U94.1, U95.1, U96.1, U97.1, U98.1, U99.1, U100.4, U101.4, U102.4, U103.4, U104.4, U105.4, U106.4, U107.4
/D1: D14.2, J1.10, U108.1, U109.1, U110.1, U111.1, U112.1, U113.1, U114.1, U115.1, U116.4, U117.4, U118.4, U119.4, U120.4, U121.4, U122.4, U123.4
/D2: D13.2, J1.11, U124.1, U125.1, U126.1, U127.1, U128.1, U129.1, U130.1, U131.1, U132.4, U133.4, U134.4, U135.4, U136.4, U137.4, U138.4, U139.4
/D3: D12.2, J1.12, U140.1, U141.1, U142.1, U143.1, U144.1, U145.1, U146.1, U147.1, U148.4, U149.4, U150.4, U151.4, U152.4, U153.4, U154.4, U155.4
/D4: D11.2, J1.13, U156.1, U157.1, U158.1, U159.1, U160.1, U161.1, U162.1, U163.1, U164.4, U165.4, U166.4, U167.4, U168.4, U169.4, U170.4, U171.4
/D5: D10.2, J1.14, U172.1, U173.1, U174.1, U175.1, U176.1, U177.1, U178.1, U179.1, U180.4, U181.4, U182.4, U183.4, U184.4, U185.4, U186.4, U187.4
/D6: D9.2, J1.15, U188.1, U189.1, U190.1, U191.1, U192.1, U193.1, U194.1, U195.1, U196.4, U197.4, U198.4, U199.4, U200.4, U201.4, U202.4, U203.4
/D7: D8.2, J1.16, U204.1, U205.1, U206.1, U207.1, U208.1, U209.1, U210.1, U211.1, U212.4, U213.4, U214.4, U215.4, U216.4, U217.4, U218.4, U219.4
/DEC3_4: D38.2, J2.1, U16.4
/DEC3_5: D39.2, J2.2, U17.4
/DEC3_6: D40.2, J2.3, U18.4
/DEC3_7: D41.2, J2.4, U19.4
/DEC4_1: D51.2, J4.1, U29.4
/DEC4_2: D52.2, J4.2, U30.4
/DEC4_3: D53.2, J4.3, U31.4
/DEC4_4: D54.2, J4.4, U32.4
/DEC4_5: D55.2, J4.5, U33.4
/DEC4_6: D56.2, J4.6, U34.4
/DEC4_7: D57.2, J4.7, U35.4
/DEC4_8: D58.2, J4.8, U36.4
/DEC4_9: D59.2, J4.9, U37.4
/DEC4_10: D60.2, J4.10, U38.4
/DEC4_11: D61.2, J4.11, U39.4
/DEC4_12: D62.2, J4.12, U40.4
/DEC4_13: D63.2, J4.13, U41.4
/DEC4_14: D64.2, J4.14, U42.4
/DEC4_15: D65.2, J4.15, U43.4
/READ_EN: D192.2, U80.1, U81.1, U82.1, U83.1, U226.4
/READ_EN_ROW_0: D102.2, U80.4, U84.6, U88.6
/READ_EN_ROW_1: D103.2, U81.4, U85.6, U89.6
/READ_EN_ROW_2: D104.2, U82.4, U86.6, U90.6
/READ_EN_ROW_3: D105.2, U83.4, U87.6, U91.6
/WRITE_ACTIVE: D191.2, U76.1, U77.1, U78.1, U79.1, U224.4
/WRITE_EN_ROW_0: D98.2, U76.4, U84.2, U88.2
/WRITE_EN_ROW_1: D99.2, U77.4, U85.2, U89.2
/WRITE_EN_ROW_2: D100.2, U78.4, U86.2, U90.2
/WRITE_EN_ROW_3: D101.2, U79.4, U87.2, U91.2
/nCE: D16.2, J1.8, U221.2
/nOE: D17.2, J1.7, U222.2
/nWE: D18.2, J1.6, U223.2, U226.2
GND: J1.1, J4.16, R1.2, R2.2, R3.2, R4.2, R5.2, R6.2, R7.2, R8.2, R9.2, R10.2, R11.2, R12.2, R13.2, R14.2, R15.2, R16.2, R17.2, R18.2, R19.2, R20.2, R21.2, R22.2, R23.2, R24.2, R25.2, R26.2, R27.2, R28.2, R29.2, R30.2, R31.2, R32.2, R33.2, R34.2, R35.2, R36.2, R37.2, R38.2, R39.2, R40.2, R41.2, R42.2, R43.2, R44.2, R45.2, R46.2, R47.2, R48.2, R49.2, R50.2, R51.2, R52.2, R53.2, R54.2, R55.2, R56.2, R57.2, R58.2, R59.2, R60.2, R61.2, R62.2, R63.2, R64.2, R65.2, R66.2, R67.2, R68.2, R69.2, R70.2, R71.2, R72.2, R73.2, R74.2, R75.2, R76.2, R77.2, R78.2, R79.2, R80.2, R81.2, R82.2, R83.2, R84.2, R85.2, R86.2, R87.2, R88.2, R89.2, R90.2, R91.2, R92.2, R93.2, R94.2, R95.2, R96.2, R97.2, R98.2, R99.2, R100.2, R101.2, R102.2, R103.2, R104.2, R105.2, R106.2, R107.2, R108.2, R109.2, R110.2, R111.2, R112.2, R113.2, R114.2, R115.2, R116.2, R117.2, R118.2, R119.2, R120.2, R121.2, R122.2, R123.2, R124.2, R125.2, R126.2, R127.2, R128.2, R129.2, R130.2, R131.2, R132.2, R133.2, R134.2, R135.2, R136.2, R137.2, R138.2, R139.2, R140.2, R141.2, R142.2, R143.2, R144.2, R145.2, R146.2, R147.2, R148.2, R149.2, R150.2, R151.2, R152.2, R153.2, R154.2, R155.2, R156.2, R157.2, R158.2, R159.2, R160.2, R161.2, R162.2, R163.2, R164.2, R165.2, R166.2, R167.2, R168.2, R169.2, R170.2, R171.2, R172.2, R173.2, R174.2, R175.2, R176.2, R177.2, R178.2, R179.2, R180.2, R181.2, R182.2, R183.2, R184.2, R185.2, R190.2, R191.2, R192.2, R193.2, R194.2, R195.2, U1.3, U2.3, U3.3, U4.3, U5.3, U6.3, U7.3, U8.3, U9.3, U10.3, U11.3, U12.3, U13.3, U14.3, U15.3, U16.3, U17.3, U18.3, U19.3, U20.3, U21.3, U22.3, U23.3, U24.3, U25.3, U26.3, U27.3, U28.3, U29.3, U30.3, U31.3, U32.3, U33.3, U34.3, U35.3, U36.3, U37.3, U38.3, U39.3, U40.3, U41.3, U42.3, U43.3, U44.3, U45.3, U46.3, U47.3, U48.3, U49.3, U50.3, U51.3, U52.3, U53.3, U54.3, U55.3, U56.3, U57.3, U58.3, U59.3, U60.3, U61.3, U62.3, U63.3, U64.3, U65.3, U66.3, U67.3, U68.3, U69.3, U70.3, U71.3, U72.3, U73.3, U74.3, U75.3, U76.3, U77.3, U78.3, U79.3, U80.3, U81.3, U82.3, U83.3, U84.4, U85.4, U86.4, U87.4, U88.4, U89.4, U90.4, U91.4, U92.3, U93.3, U94.3, U95.3, U96.3, U97.3, U98.3, U99.3, U100.3, U101.3, U102.3, U103.3, U104.3, U105.3, U106.3, U107.3, U108.3, U109.3, U110.3, U111.3, U112.3, U113.3, U114.3, U115.3, U116.3, U117.3, U118.3, U119.3, U120.3, U121.3, U122.3, U123.3, U124.3, U125.3, U126.3, U127.3, U128.3, U129.3, U130.3, U131.3, U132.3, U133.3, U134.3, U135.3, U136.3, U137.3, U138.3, U139.3, U140.3, U141.3, U142.3, U143.3, U144.3, U145.3, U146.3, U147.3, U148.3, U149.3, U150.3, U151.3, U152.3, U153.3, U154.3, U155.3, U156.3, U157.3, U158.3, U159.3, U160.3, U161.3, U162.3, U163.3, U164.3, U165.3, U166.3, U167.3, U168.3, U169.3, U170.3, U171.3, U172.3, U173.3, U174.3, U175.3, U176.3, U177.3, U178.3, U179.3, U180.3, U181.3, U182.3, U183.3, U184.3, U185.3, U186.3, U187.3, U188.3, U189.3, U190.3, U191.3, U192.3, U193.3, U194.3, U195.3, U196.3, U197.3, U198.3, U199.3, U200.3, U201.3, U202.3, U203.3, U204.3, U205.3, U206.3, U207.3, U208.3, U209.3, U210.3, U211.3, U212.3, U213.3, U214.3, U215.3, U216.3, U217.3, U218.3, U219.3, U221.3, U222.3, U223.3, U224.3, U225.3, U226.3
unnamed: D1.1, R1.1
unnamed: D2.1, R2.1
unnamed: D3.1, R3.1
unnamed: D4.1, R4.1
unnamed: D5.1, R5.1
unnamed: D6.1, R6.1
unnamed: D7.1, R7.1
unnamed: D8.1, R8.1
unnamed: D9.1, R9.1
unnamed: D10.1, R10.1
unnamed: D11.1, R11.1
unnamed: D12.1, R12.1
unnamed: D13.1, R13.1
unnamed: D14.1, R14.1
unnamed: D15.1, R15.1
unnamed: D16.1, R16.1
unnamed: D17.1, R17.1
unnamed: D18.1, R18.1
unnamed: D19.1, R19.1
unnamed: D20.1, R20.1
unnamed: D21.1, R21.1
unnamed: D22.1, R22.1
unnamed: D23.1, R23.1
unnamed: D24.1, R24.1
unnamed: D25.1, R25.1
unnamed: D26.1, R26.1
unnamed: D27.1, R27.1
unnamed: D28.1, R28.1
unnamed: D29.1, R29.1
unnamed: D30.1, R30.1
unnamed: D31.1, R31.1
unnamed: D32.1, R32.1
unnamed: D33.1, R33.1
unnamed: D34.1, R34.1
unnamed: D35.1, R35.1
unnamed: D36.1, R36.1
unnamed: D37.1, R37.1
unnamed: D38.1, R38.1
unnamed: D39.1, R39.1
unnamed: D40.1, R40.1
unnamed: D41.1, R41.1
unnamed: D42.1, R42.1
unnamed: D43.1, R43.1
unnamed: D44.1, R44.1
unnamed: D45.1, R45.1
unnamed: D46.1, R46.1
unnamed: D47.1, R47.1
unnamed: D48.1, R48.1
unnamed: D49.1, R49.1
unnamed: D50.1, R50.1
unnamed: D51.1, R51.1
unnamed: D52.1, R52.1
unnamed: D53.1, R53.1
unnamed: D54.1, R54.1
unnamed: D55.1, R55.1
unnamed: D56.1, R56.1
unnamed: D57.1, R57.1
unnamed: D58.1, R58.1
unnamed: D59.1, R59.1
unnamed: D60.1, R60.1
unnamed: D61.1, R61.1
unnamed: D62.1, R62.1
unnamed: D63.1, R63.1
unnamed: D64.1, R64.1
unnamed: D65.1, R65.1
unnamed: D66.1, R66.1
unnamed: D67.1, R67.1
unnamed: D68.1, R68.1
unnamed: D69.1, R69.1
unnamed: D70.2, U48.4, U52.2, U54.2
unnamed: D70.1, R70.1
unnamed: D71.2, U49.4, U52.1, U53.1
unnamed: D71.1, R71.1
unnamed: D72.2, U50.4, U56.2, U58.2
unnamed: D72.1, R72.1
unnamed: D73.2, U51.4, U56.1, U57.1
unnamed: D73.1, R73.1
unnamed: D74.1, R74.1
unnamed: D75.1, R75.1
unnamed: D76.1, R76.1
unnamed: D77.1, R77.1
unnamed: D78.1, R78.1
unnamed: D79.1, R79.1
unnamed: D80.1, R80.1
unnamed: D81.1, R81.1
unnamed: D82.1, R82.1
unnamed: D83.1, R83.1
unnamed: D84.1, R84.1
unnamed: D85.1, R85.1
unnamed: D86.1, R86.1
unnamed: D87.1, R87.1
unnamed: D88.1, R88.1
unnamed: D89.1, R89.1
unnamed: D90.1, R90.1
unnamed: D91.1, R91.1
unnamed: D92.1, R92.1
unnamed: D93.1, R93.1
unnamed: D94.1, R94.1
unnamed: D95.1, R95.1
unnamed: D96.1, R96.1
unnamed: D97.1, R97.1
unnamed: D98.1, R98.1
unnamed: D99.1, R99.1
unnamed: D100.1, R100.1
unnamed: D101.1, R101.1
unnamed: D102.1, R102.1
unnamed: D103.1, R103.1
unnamed: D104.1, R104.1
unnamed: D105.1, R105.1
unnamed: D106.2, U84.7, U92.2, U108.2, U124.2, U140.2, U156.2, U172.2, U188.2, U204.2
unnamed: D106.1, R106.1
unnamed: D107.2, U85.7, U93.2, U109.2, U125.2, U141.2, U157.2, U173.2, U189.2, U205.2
unnamed: D107.1, R107.1
unnamed: D108.2, U86.7, U94.2, U110.2, U126.2, U142.2, U158.2, U174.2, U190.2, U206.2
unnamed: D108.1, R108.1
unnamed: D109.2, U87.7, U95.2, U111.2, U127.2, U143.2, U159.2, U175.2, U191.2, U207.2
unnamed: D109.1, R109.1
unnamed: D110.2, U88.7, U96.2, U112.2, U128.2, U144.2, U160.2, U176.2, U192.2, U208.2
unnamed: D110.1, R110.1
unnamed: D111.2, U89.7, U97.2, U113.2, U129.2, U145.2, U161.2, U177.2, U193.2, U209.2
unnamed: D111.1, R111.1
unnamed: D112.2, U90.7, U98.2, U114.2, U130.2, U146.2, U162.2, U178.2, U194.2, U210.2
unnamed: D112.1, R112.1
unnamed: D113.2, U91.7, U99.2, U115.2, U131.2, U147.2, U163.2, U179.2, U195.2, U211.2
unnamed: D113.1, R113.1
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

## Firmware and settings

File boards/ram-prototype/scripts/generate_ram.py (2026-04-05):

#!/usr/bin/env python3
"""
Generate hierarchical KiCad schematics for the 8-byte discrete RAM prototype
with full sub-decoder trees for latency testing.

Circuit architecture (11-bit address, row/column):
  - A0-A2 -> 3-to-8 sub-decoder (4+8 ANDs) -> DEC3_0..7
  - A3-A6 -> 4-to-16 sub-decoder (8+16 ANDs) -> DEC4_0..15
  - ROW_SEL_i = AND(DEC3_i, DEC4_0) for i=0..3 (4 final ANDs)
  - Unused sub-decoder outputs go to pin headers
  - A7-A10 -> 4-to-16 column decoder -> COL_SEL_0..15
  - Active-low control: /CE, /OE, /WE -> WRITE_ACTIVE, READ_EN
  - Row enables: WRITE_EN_ROW_i = AND(WRITE_ACTIVE, ROW_SEL_i)
                 READ_EN_ROW_i  = AND(READ_EN, ROW_SEL_i)
  - Per-byte local NAND gating:
      WRITE_CLK = NAND(COL_SEL, WRITE_EN_ROW)
      BUF_OE    = NAND(COL_SEL, READ_EN_ROW)
  - 8 bytes x 8 bits = 64 D flip-flops (74LVC1G79) + 64 tri-state buffers (74LVC1G125)
  - LED on EVERY gate output and stored bit

Produces:
  ram.kicad_sch              -- root sheet with connector + bus LEDs + hierarchy refs
  address_decoder.kicad_sch  -- 7 inverters + 40 ANDs (full sub-decoder trees)
  column_select.kicad_sch    -- 4 inverters + 24 ANDs (4-to-16 column decoder)
  control_logic.kicad_sch    -- /CE,/OE,/WE inversion + WRITE_ACTIVE, READ_EN logic
  row_control.kicad_sch      -- 2 ANDs: WRITE_EN_ROW + READ_EN_ROW (shared by 4 row instances)
  byte.kicad_sch             -- 1 dual NAND (74LVC2G00) + 8 DFFs + 8 BUFs (shared by all 8 byte instances)
"""

import os
import sys

# Add shared library to path
sys.path.insert(0, os.path.normpath(os.path.join(
    os.path.dirname(__file__), "..", "..", "..", "shared", "python")))

from kicad_gen import SchematicBuilder, snap, uid, GRID, SYM_SPACING_Y
from kicad_gen.symbols import get_pin_offsets

from kiutils.items.schitems import (
    HierarchicalSheet, HierarchicalPin,
    HierarchicalSheetProjectInstance, HierarchicalSheetProjectPath,
    SymbolProjectInstance, SymbolProjectPath,
)
from kiutils.items.common import (
    Position, Property, Effects, Font, Justify, Stroke, ColorRGBA,
)

# --------------------------------------------------------------
# Constants
# --------------------------------------------------------------
PROJECT_NAME = "ram"
BOARD_DIR = os.path.normpath(os.path.join(os.path.dirname(__file__), ".."))

DFF_SPACING_Y = 13 * GRID    # vertical spacing between DFF rows in byte sheet
LED_GAP_X = 3 * GRID         # gap from output pin to LED chain center


# --------------------------------------------------------------
# Sub-sheet generators
# --------------------------------------------------------------

def generate_address_decoder():
    """
    Address decoder: 7-bit row decoder with full sub-decoder trees, 4 outputs.

    Implements a real 7-to-128 decoder structure (but only 4 final outputs):

    3-to-8 sub-decoder (A0, A1, A2) → 8 outputs:
      L1 (4 ANDs): G0=AND(/A2,/A1), G1=AND(/A2,A1), G2=AND(A2,/A1), G3=AND(A2,A1)
      L2 (8 ANDs): DEC3_n = AND(G[n>>1], A0_variant[n&1])
        DEC3_0=AND(G0,/A0), DEC3_1=AND(G0,A0), ..., DEC3_7=AND(G3,A0)

    4-to-16 sub-decoder (A3, A4, A5, A6) → 16 outputs:
      L1 group A (4 ANDs): HA0=AND(/A4,/A3), ..., HA3=AND(A4,A3)
      L1 group B (4 ANDs): HB0=AND(/A6,/A5), ..., HB3=AND(A6,A5)
      L2 (16 ANDs): DEC4_n = AND(HB[n>>2], HA[n&3])

    Final cross-product (4 ANDs):
      ROW_SEL_0 = AND(DEC3_0, DEC4_0)
      ROW_SEL_1 = AND(DEC3_1, DEC4_0)
      ROW_SEL_2 = AND(DEC3_2, DEC4_0)
      ROW_SEL_3 = AND(DEC3_3, DEC4_0)

    Unused outputs → hier labels for pin headers:
      DEC3_4..DEC3_7 (4 outputs)
      DEC4_1..DEC4_15 (15 outputs)

    Inputs:  A0-A6 (7 address bits)
    Outputs: ROW_SEL_0..3, DEC3_4..7, DEC4_1..15

    7 INV + 40 AND = 47 ICs, 47 LEDs, 47 Rs

    Layout: A1 page, 7 columns left-to-right:
      1. INV column (7 inverters)
      2. 3-to-8 L1 (4 ANDs: G0-G3)
      3. 3-to-8 L2 (8 ANDs: DEC3_0-DEC3_7)
      4. 4-to-16 L1 (8 ANDs: HA0-HA3, HB0-HB3)
      5. 4-to-16 L2 (16 ANDs: DEC4_0-DEC4_15)
      6. Final (4 ANDs: ROW_SEL_0-ROW_SEL_3)
      7. Output hier labels

    Inter-stage connections use local labels (same pattern as column_select)
    to avoid routing trunks across LED chain R_Small bodies.
    """
    b = SchematicBuilder(title="Address Decoder", page_size="A1",
                         project_name=PROJECT_NAME)
    base_x, base_y = 25.4, 30.48

    # ----------------------------------------------------------------
    # Column X positions.  All inter-column connections use local labels
    # to avoid long wires crossing through AND gate bodies.
    # ----------------------------------------------------------------
    inv_x       = snap(base_x + 20 * GRID)
    dec3_l1_x   = snap(inv_x   + 30 * GRID)      # 3-to-8 L1: G0-G3
    dec3_l2_x   = snap(dec3_l1_x + 22 * GRID)    # 3-to-8 L2: DEC3_0-DEC3_7
    dec4_l1_x   = snap(dec3_l2_x + 22 * GRID)    # 4-to-16 L1: HA0-HA3, HB0-HB3
    dec4_l2_x   = snap(dec4_l1_x + 22 * GRID)    # 4-to-16 L2: DEC4_0-DEC4_15
    final_and_x = snap(dec4_l2_x + 22 * GRID)    # Final: ROW_SEL_0-ROW_SEL_3
    hl_out_x    = snap(final_and_x + 22 * GRID)  # Output hier labels

    inv_pin_in_x = snap(inv_x - 15.24)

    # ================================================================
    # Input hier labels + inverter stage
    # ================================================================
    for i in range(7):
        addr_bit = 6 - i  # Reversed: A6 at top, A0 at bottom (matches connector visual order)
        hl_y = snap(base_y + i * 4 * GRID)
        b.add_hier_label(f"A{addr_bit}", base_x, hl_y, shape="input", justify="right")

    inv_in_pins  = []
    inv_out_pins = []
    for i in range(7):
        y = snap(base_y + i * SYM_SPACING_Y)
        _, pins = b.place_symbol("74LVC1G04", inv_x, y)
        b.connect_power(pins)
        inv_in_pins.append(pins["2"])
        inv_out_pins.append(pins["4"])

    # Route hier label → inverter input (staggered approach columns)
    approach_xs = [snap(inv_pin_in_x - (9 - i) * GRID) for i in range(7)]
    A5_STOP_X   = snap(approach_xs[2] - GRID)
    A5_DETOUR_Y = snap(base_y + 3.5 * SYM_SPACING_Y)

    for i in range(7):
        hl_y   = snap(base_y + i * 4 * GRID)
        pin_in = inv_in_pins[i]
        ax     = approach_xs[i]
        if abs(hl_y - pin_in[1]) < 0.01:
            b.add_wire(base_x, hl_y, pin_in[0], pin_in[1])
        elif i == 5:
            b.add_wire(base_x, hl_y, A5_STOP_X, hl_y)
            b.add_wire(A5_STOP_X, hl_y, A5_STOP_X, A5_DETOUR_Y)
            b.add_wire(A5_STOP_X, A5_DETOUR_Y, ax, A5_DETOUR_Y)
            b.add_wire(ax, A5_DETOUR_Y, ax, pin_in[1])
            b.add_wire(ax, pin_in[1], pin_in[0], pin_in[1])
        else:
            b.add_wire(base_x, hl_y, ax, hl_y)
            b.add_wire(ax, hl_y, ax, pin_in[1])
            b.add_wire(ax, pin_in[1], pin_in[0], pin_in[1])
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

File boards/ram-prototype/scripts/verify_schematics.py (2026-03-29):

#!/usr/bin/env python3
"""
Verification script for RAM prototype schematics.

Checks for common issues that have caused ERC failures or visual problems:
1-11. General checks via shared kicad_gen.verify module
12. Netlist connectivity (board-specific expected connections)
13. ERC via kicad-cli on the root schematic

Results are written to verify_output/ directory (gitignored).
SVGs are exported to verify_output/svg/ for visual inspection.

Usage:
    python scripts/verify_schematics.py          # Run all checks + SVG export
    python scripts/verify_schematics.py --no-erc  # Skip kicad-cli ERC and SVG export
"""

import os
import subprocess
import sys
from collections import defaultdict

# Add shared library to path
sys.path.insert(0, os.path.normpath(os.path.join(
    os.path.dirname(__file__), "..", "..", "..", "shared", "python")))

from kicad_gen.common import KICAD_CLI, snap
from kicad_gen.verify import (
    parse_schematic, run_all_checks, run_erc, UnionFind,
    _extract_lib_pins, _pin_schematic_offset, pts_close, TOLERANCE,
)
from kiutils.schematic import Schematic

# --------------------------------------------------------------
# Configuration
# --------------------------------------------------------------

BOARD_DIR = os.path.normpath(os.path.join(os.path.dirname(__file__), ".."))
OUTPUT_DIR = os.path.join(BOARD_DIR, "verify_output")

# All schematic files to check
SCHEMATIC_FILES = [
    "ram.kicad_sch",
    "address_decoder.kicad_sch",
    "column_select.kicad_sch",
    "control_logic.kicad_sch",
    "row_control.kicad_sch",
    "byte.kicad_sch",
    "power_supply.kicad_sch",
]


# --------------------------------------------------------------
# Netlist verification (board-specific)
# --------------------------------------------------------------

def check_netlist():
    """Verify root sheet netlist connectivity.

    Builds nets from wire connectivity in ram.kicad_sch using union-find,
    then checks that expected pairs of hierarchy sheet pins are on the same
    net (e.g., address decoder SEL0 -> write_clk_gen SEL0) and that signals
    that should be separate are NOT merged.

    Returns list of issue strings (empty if all checks pass).
    """
    filepath = os.path.join(BOARD_DIR, "ram.kicad_sch")
    if not os.path.exists(filepath):
        return ["  ram.kicad_sch not found"]

    sch = Schematic.from_file(filepath)
    uf = UnionFind()

    # -- Collect wires --
    wires = []
    for item in sch.graphicalItems:
        if getattr(item, 'type', None) == 'wire':
            pts = item.points
            if len(pts) >= 2:
                p1 = (snap(pts[0].X), snap(pts[0].Y))
                p2 = (snap(pts[1].X), snap(pts[1].Y))
                wires.append((p1, p2))
                uf.union(p1, p2)

    # -- Collect all electrically-active points --
    all_pts = set()
    for p1, p2 in wires:
        all_pts.add(p1)
        all_pts.add(p2)

    # Sheet pins: map (x,y) -> "SheetName:PinName"
    sheet_pin_ids = {}
    for sheet in sch.sheets:
        sname = sheet.sheetName.value
        for pin in sheet.pins:
            pt = (snap(pin.position.X), snap(pin.position.Y))
            sheet_pin_ids[pt] = f"{sname}:{pin.name}"
            all_pts.add(pt)

    # Labels: map (x,y) -> label text
    label_pts = {}
    for lbl in getattr(sch, 'labels', []):
        pt = (snap(lbl.position.X), snap(lbl.position.Y))
        label_pts[pt] = lbl.text
        all_pts.add(pt)

    # Component pins (connector, LEDs, resistors)
    lib_pin_map = {}
    for lib_sym in sch.libSymbols:
        lib_pin_map[lib_sym.libId] = _extract_lib_pins(lib_sym)

    comp_pin_ids = {}  # (x,y) -> "Ref:pin_num"
    for comp in sch.schematicSymbols:
        lib_id = comp.libId
        cx, cy = snap(comp.position.X), snap(comp.position.Y)
        angle = comp.position.angle or 0
        ref = "?"
        for prop in comp.properties:
            if prop.key == "Reference":
                ref = prop.value
                break
        if lib_id in lib_pin_map:
            for pin_num, lx, ly, pa, pl in lib_pin_map[lib_id]:
                dx, dy = _pin_schematic_offset(lx, ly, angle)
                pt = (snap(cx + dx), snap(cy + dy))
                comp_pin_ids[pt] = f"{ref}:{pin_num}"
                all_pts.add(pt)

    # Junctions
    for j in sch.junctions:
        all_pts.add((snap(j.position.X), snap(j.position.Y)))

    # -- Merge points that touch wires (T-junctions + endpoints) --
    for pt in all_pts:
        for (x1, y1), (x2, y2) in wires:
            if abs(y1 - y2) < TOLERANCE:  # horizontal
                xmin, xmax = min(x1, x2), max(x1, x2)
                if (abs(pt[1] - y1) < TOLERANCE and
                        xmin - TOLERANCE <= pt[0] <= xmax + TOLERANCE):
                    uf.union(pt, (x1, y1))
            elif abs(x1 - x2) < TOLERANCE:  # vertical
                ymin, ymax = min(y1, y2), max(y1, y2)
                if (abs(pt[0] - x1) < TOLERANCE and
                        ymin - TOLERANCE <= pt[1] <= ymax + TOLERANCE):
                    uf.union(pt, (x1, y1))

    # -- Merge same-name labels (implicit net connections) --
    label_groups = defaultdict(list)
    for pt, name in label_pts.items():
        label_groups[name].append(pt)
    for name, pts in label_groups.items():
        for i in range(1, len(pts)):
            uf.union(pts[0], pts[i])

    # -- Build net membership: root -> set of identifiers --
    nets = defaultdict(set)
    for pt, sid in sheet_pin_ids.items():
        nets[uf.find(pt)].add(sid)
    for pt, name in label_pts.items():
        nets[uf.find(pt)].add(f"label:{name}")

    def on_same_net(id_a, id_b):
        for root, members in nets.items():
            if id_a in members and id_b in members:
                return True
        return False

    def id_exists(identifier):
        return any(identifier in m for m in nets.values())

    # -- Define expected connections --
    issues = []

    # 1. ROW_SEL_0-3: addr decoder -> Row Control i
    for i in range(4):
        ad = f"Address Decoder:ROW_SEL_{i}"
        rc = f"Row Control {i}:ROW_SEL"
        if not on_same_net(ad, rc):
            issues.append(f"  {ad} not connected to {rc}")

    # 2. WRITE_ACTIVE: control logic -> all Row Control blocks
    for i in range(4):
        rc = f"Row Control {i}:WRITE_ACTIVE"
        if not on_same_net("Control Logic:WRITE_ACTIVE", rc):
            issues.append(
                f"  Control Logic:WRITE_ACTIVE not connected to {rc}")

    # 3. READ_EN: control logic -> all Row Control blocks
    for i in range(4):
        rc = f"Row Control {i}:READ_EN"
        if not on_same_net("Control Logic:READ_EN", rc):
            issues.append(
                f"  Control Logic:READ_EN not connected to {rc}")
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

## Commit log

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2026-02-23 Fix all ERC checks
    [address_decoder.kicad_sch, byte.kicad_sch, control_logic.kicad_sch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]
2026-02-23 fix duplicate id issues
    [address_decoder.kicad_sch, byte.kicad_sch, control_logic.kicad_sch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]
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2026-02-23 Fix ERC issues
    [address_decoder.kicad_sch, byte.kicad_sch, control_logic.kicad_sch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]
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2026-02-24 Fix a bunch of issues
    [address_decoder.kicad_sch, byte.kicad_sch, control_logic.kicad_sch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]
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2026-02-25 fixup root page
    [address_decoder.kicad_sch, byte.kicad_sch, control_logic.kicad_sch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]
2026-02-27 add and fix some checks
    [address_decoder.kicad_sch, byte.kicad_sch, control_logic.kicad_sch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]
2026-02-27 Fix labelling
    [address_decoder.kicad_sch, byte.kicad_sch, control_logic.kicad_sch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]
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2026-02-27 fix remaining warnings
    [address_decoder.kicad_sch, byte.kicad_sch, control_logic.kicad_sch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]
2026-02-27 fix fanout
    [address_decoder.kicad_sch, byte.kicad_sch, control_logic.kicad_sch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]
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2026-02-27 fix a lot of issues
    [ram.kicad_pcb]
2026-02-28 fix location of pcb
    [ram.kicad_pcb]
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2026-03-01 Fix errors from autorouting
    [ram.kicad_pcb, ram_routed.kicad_pcb]
2026-03-01 Fix some pcb drc warnings
    [ram.kicad_pcb]
2026-03-01 Fix more drc errors
    [address_decoder.kicad_sch, byte.kicad_sch, control_logic.kicad_sch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]
2026-03-01 fix some of the routing
    [ram.kicad_pcb, ram_routed.kicad_pcb]
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2026-03-03 fix many issues
    [address_decoder.kicad_sch, byte.kicad_sch, control_logic.kicad_sch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]
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2026-03-08 fix issues
    [ram.kicad_pcb, ram_routed.kicad_pcb]
2026-03-08 flip resistor to the back
    [ram.kicad_pcb, ram_routed.kicad_pcb]
2026-03-09 Fix some layer issues
    [address_decoder.kicad_sch, byte.kicad_sch, control_logic.kicad_sch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]
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2026-03-10 rotate buffer and flip flop for better routing
    [ram.kicad_pcb]
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2026-03-11 Fix more issues
    [address_decoder.kicad_sch, byte.kicad_sch, column_select.kicad_sch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]
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2026-03-11 Fix rotation confusion
    [ram.kicad_pcb]
2026-03-11 Fix weird angles
    [ram.kicad_pcb]
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2026-03-12 fix pin numbering
    [ram.kicad_pcb]
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2026-03-12 Clean up warning skip list
    [ram.kicad_pcb]
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2026-03-14 route between flipflop and buffer
    [ram.kicad_pcb]
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2026-03-16 put vias in the correct spot
    [ram.kicad_pcb]
2026-03-16 fix some routing issues
    [ram.kicad_pcb]
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2026-03-17 fix leds and compress bytes
    [ram.kicad_pcb]
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2026-03-29 bottom-justify connector and add column_select routing buffer
    Aligns the main connector to the bottom board edge instead of centering
    it vertically. Adds 10mm routing buffer below column_select block.
    Pin labels are left-justified to avoid silk edge/copper overlap.
    [ram.kicad_pcb]
2026-03-29 fix connector 3D model orientation and layer placement
    J1 (main connector) stays on B.Cu with 180° Z model rotation to
    compensate for the B.Cu mirror. J2-J4 (test headers) moved from
    B.Cu to F.Cu so pins face out the top of the board normally.
    [ram.kicad_pcb]
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2026-03-29 add vertical D* data bus column trunks on In1.Cu
    Route D0-D7 vertical trunks on In1.Cu connecting the 4 bytes in each
    byte column. Uses horizontal stubs from existing DFF-BUF data vias to
    a trunk line at ic_x+0.05 (0.55mm from VCC vias, 0.30mm clearance).
    112 trace segments total. DRC clean on Default/PCBWay/Elecrow rules.
    Also changed DFF-BUF data vias from remove_unused_layers to explicit
    F.Cu/In1.Cu layers so the column trunks can connect.
    [ram.kicad_pcb]
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2026-03-29 side-by-side LED+R layout for non-byte groups, rotate column_select 90° CW
    - Place R beside LED (R_HORIZ_OFFSET=1.3mm) instead of below for all
    non-byte logic groups (addr_decoder, column_select, control_logic,
    row_ctrl). Byte groups keep stacked R below LED (tight spacing).
    - R at 90° (pad 1 at bottom) matches LED cathode position for a simple
    straight trace connection instead of the old 3-segment route.
    - Restructure column_select from horizontal rows to vertical columns
    (matching addr_decoder pattern), then rotate entire group 90° CW so
    L2 outputs are closest to RAM block.
    - Fix preroute_r_gnd to identify NAND Rs by their associated LED angle
    (0°) instead of R angle (180°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
    [ram.kicad_pcb]
2026-03-29 side-by-side mirrored NAND LED layout with 45° local routing
    Place byte-level write/read LEDs horizontally adjacent instead of
    vertically stacked. Mirrored orientation so R GND pads face inward,
    with shared GND via centered below. All LED-to-R and GND traces
    routed at 45° angles. Increase GROUP_GAP_Y to 0.75mm to maintain
    enable bus clearance between byte rows.
    [ram.kicad_pcb]
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2026-03-29 add VCC/GND power vias to all logic ICs (INV, AND)
    178 new vias for 89 logic ICs (14 inverters + 75 AND gates).
    DFF/BUF/NAND already handled by dedicated preroute functions.
    ICs at 180°: GND escapes 30° down-right (d=0.55mm), VCC escapes
    135° down-left — threads between IC→LED trace, pin 2, and LED pad.
    Other angles use diagonal-away-from-center escape.
    Default DRC: 0 errors, 0 warnings.
    [ram.kicad_pcb]
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2026-03-29 R GND vias escape right, add IC→LED routing for rotated column_select
    - Change R@90° GND via escape from UP (270°) to RIGHT (0°)
    - Add 270° IC→LED 3-segment routing (LEFT-UP-RIGHT) for rotated
    column_select ICs — mirrors the 180° pattern rotated 90° CW
    - Add 270° GND power via escape at 300° (up-right, d=0.55mm)
    to avoid new IC→LED traces
    - IC→LED traces: 311 → 395 (+84 = 28 column_select ICs × 3 segs)
    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
    [ram.kicad_pcb]
2026-03-29 R GND vias escape right/up, IC→LED for rotated column_select
    - R@90° (decoder/ctrl): GND escape changed from UP to RIGHT
    - R@180° (rotated col_select): GND escape changed from LEFT to UP
    (away from LED below)
    column_select ICs — mirrors the 180° UP-RIGHT-DOWN pattern
    - Fix C_Small crash: filter non-connector parts from extra_root list
    - IC→LED traces: 311 → 395 (+84 segments)
    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
    [ram.kicad_pcb]
2026-03-30 add PCB layout for power supply section with custom TPS546D24A footprint
    Places all 19 power supply components at the top-left corner of the
    board, above the existing logic. Creates custom LQFN-CLIP-40 footprint
    (5mm x 7mm, 0.5mm pitch) from TI RVF0040A datasheet land pattern.
    Layout: Molex Mini-Fit Jr 2x4 (no mounting pegs) -> input caps ->
    TPS546D24A with bypass caps tight against QFN -> inductor -> output
    caps in 2 rows. PGOOD LED indicator below. All power components left
    of RAM (8.5mm margin).
    Changes:
    - power_footprints.py: generates TPS546D24A_LQFN-CLIP-40 + SMD connector
    - generate_pcb.py: power_supply group handling, fp_override for 0805 caps,
    Conn_02x support, 28mm Y shift for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
    [ram.kicad_pcb]
2026-03-30 add copper pours, thermal vias, and SW keepout for power supply layout
    Rotates TPS546D24A 180° so PVIN faces input caps (left) and SW faces
    inductor (right), matching datasheet layout recommendation (Fig 10-1).
    Copper pours (F.Cu, regional):
    - PVIN pour: input caps to PVIN pins, solid pad connection
    - PGND pour: around thermal pad, connects vias to PGND pins
    - VOUT pour: inductor output through output caps to VCC
    - SW keepout zone: prevents fill in switching node area
    Thermal vias: 2x3 grid (6 vias, 0.3mm drill) under exposed pad,
    connecting F.Cu to B.Cu GND plane per datasheet land pattern.
    Bypass caps repositioned for 180° IC rotation:
    - C3 (PVIN HF) + C5 (VDD5): left side near respec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
    [ram.kicad_pcb]
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2026-03-30 improve power supply schematic layout and symbol
    - Replace BOOT_INT/VDD5_INT/BP1V5_INT labels with direct-wire horizontal
    bypass caps (angle=90) at staggered X offsets to avoid component overlap
    - Replace PGOOD label + disconnected section with direct-wire pullup + LED
    at PGD pin (half-grid Y offset to avoid T-junction with boot L-route)
    - Move output cap row down (16G from inductor vs 10G) for text clearance
    - Remove dangling PWR_FLAG+VCC from end of output cap chain, place PWR_FLAG
    at inductor output instead
    - Tighten layout: input caps 20G (was 25G), EN divider 8G (was 12G)
    - TPS546D24A symbol: SW pin 8 changed to power_out (drives SW net)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
    [address_decoder.kicad_sch, byte.kicad_sch, column_select.kicad_sch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]
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2026-03-31 add text overlap check to schematic verification and fix all violations
    New check #12 in verify.py detects text overlapping wires, component
    bodies, or other text. Smart exclusions for labels on their connection
    wire and same-component Reference/Value pairs avoid false positives.
    Fixes in generate_ram.py:
    - Move ROW_SEL trunk wires from col2_x-3*GRID to col2_x-7*GRID so
    WRITE_ACTIVE/READ_EN labels don't overlap them
    - Power supply: switch VDD5/BP1V5 bypass caps to angle=0 (vertical)
    with L-routes and 4*GRID vertical drop from IC pins
    - Power supply: separate PGD L-route vertical X from pull-up resistor X
    - Power supply: hide boot cap value (pin 2 wire unavoidably crosses it)
    Co-Authore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
    [address_decoder.kicad_sch, byte.kicad_sch, column_select.kicad_sch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]
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2026-03-31 route D* data bus from byte grid fanout to connector on F.Cu
    Add preroute_dbus_to_connector() that routes all 8 D-bus signals
    from the byte grid fanout to the connector LED stubs entirely on
    F.Cu, going around the address decoder and control logic groups.
    Route geometry per signal:
    - Staggered horizontal extension (fans traces for 0.61mm diagonal
    perpendicular spacing via 0.253mm X-stagger per trace)
    - 45° diagonal DOWN-LEFT from byte grid to bus corridor below
    control logic (y≈121-125)
    - Natural peel-off transition to horizontal bus at 0.61mm spacing
    - Horizontal bus LEFT through clear corridor
    - Chamfered 45° fan to connector stub endpoints
    Automatic via avoidance scans existing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
    [ram.kicad_pcb]
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2026-03-31 route A7-A10 column address bus from connector to column select
    Add preroute_coladdr_to_colsel() that routes the 4 column address
    signals (A7-A10) as a parallel horizontal bus from the connector
    LED stubs to near the column_select inverter inputs on F.Cu.
    The bus runs ~75mm horizontally at 2.54mm spacing (connector pitch)
    through the clear corridor below the D* bus and byte grid. The
    signal-to-INV mapping is reversed (A7→leftmost, A10→rightmost)
    so a non-crossing 45° fan is impossible on a single layer — the
    bus stops at the earliest peel-off point and the autorouter handles
    the final ~12mm to each INV pin.
    Also regenerates schematics to sync with latest generate_ram.py.
    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
    [address_decoder.kicad_sch, byte.kicad_sch, column_select.kicad_sch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]
2026-03-31 swap DSBGA-8 gate pins and locally route all NAND connections
    Gate swap (pins 1↔5, 2↔6, 3↔7) in the DSBGA-8 footprint puts CLK
    output on the top row and OE output on the bottom row at 270° rotation,
    enabling natural routing directions for both outputs.
    Full local prerouting for all NAND signals:
    - CLK: F.Cu UP to bus, In1.Cu bypass under READ_EN to DFFs, F.Cu LEFT
    column DOWN to left LED
    - OE: F.Cu DOWN-RIGHT to right LED (swapped), 45° past R to OE bus
    column, F.Cu RIGHT to BUF OE stubs
    - WRITE_EN: F.Cu straight DOWN through widened LED gap to bus (swapped
    below OE bus)
    - READ_EN: F.Cu straight UP to bus (swapped above CLK bus)
    - GND/VCC: 45° escapes to vias
    - COL_SEL: both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
    [ram.kicad_pcb, ram_routed.kicad_pcb]
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2026-03-31 add routing keepouts for RAM byte grid and layer test grid
    Inject keepout regions into Specctra DSN before FreeRouting runs,
    preventing the autorouter from routing through the dense byte grid
    and layer test grid areas on F.Cu and In1.Cu. Uses DSN-level injection
    (not KiCad keepout zones) to avoid DRC conflicts with pre-routed traces.
    - Add PCBBuilder.add_routing_keepout() method for KiCad-level keepouts
    - generate_pcb.py writes routing_keepouts.json with keepout coordinates
    - route_pcb.py reads JSON and injects (keepout ...) into DSN after export
    [ram.kicad_pcb]
2026-03-31 replace J4 with 2-row connector and reposition J2/J4 headers
    - Change J4 (DEC4 unused outputs) from Conn_01x16 to Conn_02x08_Odd_Even
    (2-row vertical pin header, more compact than 16-pin single row)
    - Move J2 (DEC3) to top-left corner above main connector
    - Move J4 (DEC4) to left of test grid, vertical orientation
    - Add Conn_02x08_Odd_Even to symbol/footprint library maps
    - Board size: 173 x 118 mm (down from 233 x 95 mm)
    - 0 ERC errors/warnings, 0 DRC errors/warnings
    [address_decoder.kicad_sch, byte.kicad_sch, column_select.kicad_sch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]
2026-03-31 add center escape routing for DSBGA-5 middle pin (B1->B2 gap)
    Routes pin 2 of AND/INV ICs through the IC center to the empty B2
    ball position, giving the autorouter an accessible stub endpoint.
    89 escape traces across address decoder, column select, control
    logic, and row control groups. DFFs/BUFs skipped (already routed).
    [ram.kicad_pcb]
2026-03-31 swap D* and ctrl pins on connector, move ctrl logic below power supply
    Data bus (D0-D7) now at pins 9-16, control (nCE/nWE/nOE) at pins 6-8.
    Control Logic sheet block repositioned below Power Supply in col2.
    [address_decoder.kicad_sch, byte.kicad_sch, column_select.kicad_sch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]
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2026-03-31 update PCB layout for connector pin swap
    - Update silkscreen pin labels to match new connector pinout
    (nCE/nWE/nOE at pins 6-8, D0-D7 at pins 9-16)
    - Shift ctrl_logic left (col1_x - 2.0) to clear D-bus diagonal path
    - Defer D*-to-connector routing to autorouter — the diagonal path
    now crosses ctrl_logic and A7-A10 areas, better handled multi-layer
    [ram.kicad_pcb]
2026-03-31 route D* bus above control logic, restore A7-A10 prerouting
    - Move ctrl_logic down 7mm below decoder (CTRL_DBUS_GAP=7.0) to create
    a corridor for the D* bus between decoder bottom and ctrl_logic top
    - D* bus corridor at y≈102-106, ctrl_logic at y≈110, A7-A10 below both
    - Add obs_y_max filter to preroute_dbus_to_connector so it ignores
    ctrl_logic footprints when computing bus corridor Y
    - Restrict obstacle scan to decoder area (x>35) to avoid connector LEDs
    - Re-enable A7-A10 prerouting (now clears ctrl_logic)
    - Update connector silkscreen labels for swapped pin assignment
    [ram.kicad_pcb]
2026-03-31 regenerate all schematics and PCB from scripts
    Freshly generated to ensure consistency after rebase.
    0 ERC errors/warnings, 0 DRC errors/warnings.
    [address_decoder.kicad_sch, byte.kicad_sch, column_select.kicad_sch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]
2026-03-31 route WRITE_ACTIVE and READ_EN vertical trunks on In1.Cu
    Add preroute_ctrl_enable_trunks: routes both control enable signals
    from row_ctrl AND gates on In1.Cu vertical trunks.
    WRITE_ACTIVE trunk at ic_center_x with gaps where READ_EN horizontal
    jogs cross. READ_EN trunk at ic_x+1.24 under the LED+R area. Both
    use 0.34mm F.Cu escape stubs from pin 1 to vias with
    remove_unused_layers. 8 vias + 25 traces total.
    Also adds center escape for DSBGA-5 pin 2 (B1->B2 gap) on AND/INV
    ICs (skipping control_logic and row_ctrl groups), and
    remove_unused_layers parameter to PCBBuilder.pin_to_via().
    0 errors, 0 warnings across Default/PCBWay/Elecrow rulesets.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
    [ram.kicad_pcb]
2026-03-31 add pin 2 escape stubs for row_ctrl/control_logic, fix WRITE_ACTIVE trunk, improve FreeRouting clearances
    - Remove skip of control_logic and row_ctrl ICs from preroute_center_escape
    so pin 2 (middle ball) gets escape stubs — reduces unconnected items from
    176 to 15
    - Move READ_EN vias right of WRITE_ACTIVE trunk so horizontal jogs don't
    cross it, making WRITE_ACTIVE one uninterrupted vertical line
    - Add Connectors net class for J2/J3/J4 secondary headers in .kicad_pro
    - Fix DSN clearances: smd_smd 37.5µm→150µm, add via_via/via_smd/via_pin
    250µm to match KiCad DRC settings
    - Increase verify timeout from 120s to 600s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
    [ram.kicad_pcb, ram_routed.kicad_pcb]
2026-04-01 fix pad coordinate precision, extend ram keepout, match fab clearance rules
    - Increase get_pad_position() and add_trace() precision from 2 to 3 decimals
    (0.01mm -> 0.001mm). Fixes 5µm mismatch between trace endpoints and DSBGA
    pad positions that caused dangling track cleanup to delete NAND LED traces
    - Extend ram_grid routing keepout to cover D* bus horizontal traces below
    byte grid (y2: 81.38 -> 86.67), stops before COL_SEL vias
    - Match DSN clearances to actual PCBWay/Elecrow fab rules: via-to-track and
    via-to-via use 10mil (0.254mm) not 0.25mm. Eliminates all hole_clearance
    DRC violations. Post-routing errors: 271 -> 36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
    [ram.kicad_pcb, ram_routed.kicad_pcb]
2026-04-01 fix NAND LED anode route, COL_SEL trunk gap, and pad index precision
    - Fix CLK LED approach route: T-branch from clk_pos[0] instead of
    clk_via_x (0.05mm gap caused dangling cleanup to delete LED route)
    - Fix COL_SEL trunk extension: use actual bottom pin Y from
    get_pad_position() instead of hardcoded crtyd_bot_y (0.55mm gap)
    - Increase _build_net_pad_index precision to 3 decimals to match
    get_pad_position/add_trace precision
    - Save raw post-SES-import PCB to verify_output/ for inspection
    - Post-routing: 36 errors -> 3 (1 nCE unconnected + 2 solder mask)
    [ram.kicad_pcb, ram_routed.kicad_pcb]
2026-04-01 reorder connector control pins to nCE/nOE/nWE top-to-bottom
    Move nCE to pin 8 (top), nOE to pin 7, nWE to pin 6 (bottom) on the
    24-pin connector. Previous order was nCE/nWE/nOE which put nCE at the
    bottom, making it harder for the autorouter to reach control_logic.
    Post-routing: 3 errors (2 solder mask bridge), 3 warnings. The nCE
    unconnected error from the previous run is eliminated.
    [address_decoder.kicad_sch, byte.kicad_sch, column_select.kicad_sch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]
2026-04-01 fully local COL_SEL routing, connector keepout, cleanup and clearance fixes
    - Route COL_SEL_0/1 from terminus vias to column select ICs entirely on
    F.Cu with chamfered 45° paths (no autorouter needed for these nets)
    - Add connector keepout zone covering J1 and bus indicator LEDs
    - Move LED/R blocks 2mm closer to connector (led_x: 7→5)
    - Fix DSN clearances: global 200µm (PCBWay pad-to-track), via_via 500µm
    (PCBWay hole-to-hole different nets), smd_smd 154µm, via_smd/pin 254µm
    - Power via collision check: skip placement if within 0.8mm of existing via
    - Increase dangling track cleanup limit from 10mm to 50mm
    - Fix _buil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
    [ram.kicad_pcb, ram_routed.kicad_pcb]
2026-04-01 add via_via clearance to per-class DSN rule blocks
    FreeRouting ignores global rules for nets assigned to a class, so
    via_via/via_smd/via_pin clearances must be in every per-class rule
    block. Previously only the global block had them, causing autorouted
    vias to violate PCBWay/Elecrow hole-to-hole clearance (0.5mm).
    PCBWay/Elecrow DRC: 9 hole_to_hole errors → 0
    [ram_routed.kicad_pcb]
2026-04-01 strip R/DSBGA silk, reposition LED polarity dot, update docs
    - Remove silkscreen from 0402 resistor and DSBGA IC footprints (too
    dense for PCBWay 0.15mm silk clearance)
    - Reposition LED polarity dot: Y offset -0.38mm to clear solder mask,
    stroke width reduced to 0.05mm. Keeps polarity visible near cathode
    - Update silk_overlap skip comment (now LED dot vs adjacent R, not
    stock 0402 outline)
    - Update CLAUDE.md: FreeRouting DSN lessons (per-class rules, 10mil
    clearances, no routing priority), pad precision bug, board dimensions
    - Update todo.md: mark completed routing/pre-routing/silkscreen tasks
    [ram.kicad_pcb, ram_routed.kicad_pcb]
2026-04-01 fix silk_overlap: strip DSBGA-8/R silk, LED dot to F.Fab, remove skip
    - Strip silkscreen from DSBGA-8 (too close to pads) and 0402 resistors
    - Keep DSBGA-5/6 silkscreen (no violations)
    - Move LED polarity dot from F.SilkS to F.Fab (visible in KiCad, no
    DRC conflicts at any rotation)
    - Remove silk_overlap from DRC skip lists — now passes clean on both
    Default and PCBWay rules
    - Update CLAUDE.md skip_types documentation
    [ram.kicad_pcb]
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2026-04-01 add full 2KB RAM board (boards/ram/) with 4-level hierarchy
    New board: 128 rows x 16 columns x 8 bits = 2048 bytes of discrete RAM.
    35,278 ICs, 20,964 LEDs, 77,222 total parts across a 4-level schematic
    hierarchy (root -> row_group x16 -> row x128 -> byte x2048).
    Shares 5 sub-sheet generators with the prototype (column_select,
    control_logic, row_control, byte, power_supply). New sheets: row_group
    (8 final AND gates + 8 row refs) and row (row_control + 16 byte refs).
    Also fixes label text justification in shared SchematicBuilder to default
    to "left" instead of center, matching KiCad's native behavior. Regenerates
    prototype schematics with this fix.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
    [address_decoder.kicad_sch, byte.kicad_sch, column_select.kicad_sch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]
2026-04-01 tighten LED-R spacing, fix DSN clearance separator investigation
    - Reduce R_HORIZ_OFFSET from 1.3mm to 1.0mm (LED-R closer together
    for standard logic gates). Board shrinks from 171x118 to 170x117mm
    - Investigated FreeRouting CLASS_CLEARANCE_SEPARATOR: '-' vs '_'.
    Hyphens are parsed but produce worse results (11 hole_to_hole vs 2).
    Reverted to underscores — FreeRouting ignores them and uses global
    clearance as baseline, which works better in practice
    - PCBWay: 2 hole_to_hole violations remain (0.48mm vs 0.50mm required)
    — autorouted vias near pre-routed power vias, FreeRouting limitation
    [ram.kicad_pcb, ram_routed.kicad_pcb]
2026-04-02 keep LED polarity dot on F.SilkS, shift to clear adjacent R pads
    Move LED polarity dot from F.Fab back to F.SilkS so it prints on the
    PCB silkscreen. Shift dot center to (-0.5, -0.55) in footprint-local
    coords (with Y-flip for specific refs) to clear 0.15mm silk_overlap
    rule against adjacent resistor pads. Rewrite remove_silkscreen_graphics
    as text-based processing to avoid kiutils corrupting routed PCB tstamps.
    Rerouted board passes DRC with 0 silk_overlap violations on all rule sets.
    [ram.kicad_pcb, ram_routed.kicad_pcb]
2026-04-02 widen decoder column spacing to fix hole_to_hole DRC violations
    Increase col_sp from 7.5mm to 8.5mm in both addr_decoder and
    column_select layouts. The extra 1mm per column gap gives FreeRouting
    enough room to place vias without violating PCBWay/Elecrow 0.5mm
    hole-to-hole clearance. Board grows modestly from 170x117 to 175x120mm.
    Post-routing DRC now passes on all three rule sets (Default, PCBWay,
    Elecrow) with only the pre-existing cosmetic solder_mask_bridge and
    isolated_copper warnings remaining.
    [ram.kicad_pcb, ram_routed.kicad_pcb]
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2026-04-04 use no-net zones for test grid fills to fix isolated_copper DRC warnings
    Test grid F.Cu/In1.Cu zones were assigned to GND but surrounded by
    keepouts, making them isolated from the main GND net. Changed to
    no-net ("") since they're cosmetic test fills, not circuit copper.
    [ram.kicad_pcb, ram_routed.kicad_pcb]
2026-04-05 port to Linux / KiCad 10
    Auto-detect KICAD_CLI, KICAD_PYTHON, KICAD_FP_DIR, KICAD_SYM_DIR per
    platform instead of hardcoding Windows "C:\Program Files\KiCad\9.0"
    paths; environment variables override. _detect_kicad_python() probes
    for pcbnew so it skips the venv python (no pcbnew) and picks the
    system python3 the KiCad apt package installs into.
    KiCad 10 ERC treats a label as "dangling" unless its net contains a
    symbol pin in the same sheet -- sub-sheet pins behind a hierarchy
    block don't count. Add SchematicBuilder.place_pin_anchor(), which
    drops a hidden Connector:TestPoint (ref prefix #TP, in_bom=False)
    whose pin 1 lands exactly on the label position. The #TP prefix
    keeps it out of th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
    [address_decoder.kicad_sch, byte.kicad_sch, column_select.kicad_sch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]
